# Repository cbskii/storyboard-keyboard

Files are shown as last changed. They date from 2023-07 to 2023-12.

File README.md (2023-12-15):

# Storyboard Keyboard PCB

The "Storyboard" is a 5x12 ortholinear keyboard with an E-Paper display in the middle. This is a hobby project so I've designed the keyboard with learning and experimentation in mind. Most components are SMT and can be assembled by the PCB manufacturer for added cost leaving only a few headers to be soldered by hand. The `production_files` directory contains gerber files and a BOM needed for PCB manufacturing.

## Features
- Ortholinear "split" 5x12 key arrangement.
- Hot swap key switches with split FR4 plates.
- Fits standard sized 60% keyboard cases that use a USB daughterboard (e.g. Tofu60 and Bakeneko60).
- E-Paper display for personalization. The [3.7" Waveshare e-Paper HAT](https://www.waveshare.com/3.7inch-e-paper-hat.htm) fits the best and is supported by the firmware, but the 3.52" would work as well if firmware support is added. Last set image will remain even when keyboard is unplugged/powered off (but recommended to refresh the display every now and then by rebooting the keyboard).
- USB daughterboard support (e.g. [Unified Daughterboard](https://github.com/Unified-Daughterboard/)).
- Support for different [Sparkfun Micromod](https://www.sparkfun.com/micromod) processor boards allowing for easy swap of the underlying MCU and related functionality (requires firmware change).
- QMK firmware ([development branch](https://github.com/cbskii/qmk_firmware/tree/master/keyboards/storyboard)).
- Shift register based key matrix that requires only 4 GPIOs.
- Key press interrupt support to enable lower power usage modes.

## Inspiration
- [Lumberjack](https://github.com/peej/lumberjack-keyboard)
- [Ghoul](https://github.com/tzarc/ghoul)
- [Bakeneko 60](https://github.com/kkatano/bakeneko-60)

## Pictures
storyboard-space
storyboard-rev1-front
storyboard-rev1-back

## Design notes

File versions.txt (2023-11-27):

Revision History
----------------
1.0: Initial Schematic and PCB.
1.1: Add top mount plates for Tofu60. Move from 3.52" display to 3.7".

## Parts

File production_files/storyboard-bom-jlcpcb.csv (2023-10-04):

Comment | Designator | Footprint | JLCPCB Part # | SMD Assembly
Kailh_socket_MX | SW51,SW16,SW9,SW35,SW28,SW19,SW38,SW11,SW15,SW47,SW17,SW23,SW41,SW13,SW44,SW45,SW56,SW8,SW59,SW34,SW26,SW36,SW25,SW50,SW54,SW53,SW37,SW18,SW4,SW46,SW33,SW14,SW52,SW3,SW58,SW40,SW43,SW55,SW12,SW6,SW21,SW48,SW32,SW5,SW39,SW49,SW20,SW7,SW29,SW57,SW10,SW42,SW27,SW24,SW60,SW30,SW31,SW1,SW22,SW2 | Kailh_socket_MX | C5156480 | Yes
AP7361C-33E | U4 | SOT-223-3_TabPin2 | C500795 | Yes
10k | R11,R6,R16,R14,R20,R12,R18,R1,R19,R8,R13,R17,R15,R5,R7,R10,R9,R3,R4,R2 | R_0805_2012Metric | C2930231 | Yes
1N4148 | D8,D35,D56,D21,D9,D33,D57,D7,D34,D62,D36,D15,D11,D17,D29,D39,D49,D40,D63,D59,D24,D32,D12,D20,D42,D38,D46,D4,D45,D47,D28,D54,D61,D50,D58,D22,D66,D13,D68,D72,D41,D44,D69,D70,D65,D6,D10,D31,D67,D73,D3,D18,D16,D23,D2,D30,D25,D1,D60,D5,D26,D51,D27,D55,D71,D52,D64,D37,D43,D53,D14,D48,D19 | D_SOD-523 | C727112 | Yes
74HC165 | U3,U2 | SOIC-16_3.9x9.9mm_P1.27mm | C5613 | Yes
CONN HEADER SMD 4POS 1.2MM | J2 | CONN HEADER SMD 4POS 1.2MM | C588524 | Yes
74HC164 | U1 | SOIC-14_3.9x8.7mm_P1.27mm | C5419 | Yes
4.7uF | C4,C5 | C_0805_2012Metric | C98192 | Yes
0.1uF | C3,C2,C1 | C_0805_2012Metric | C126469 | Yes
CONN M.2 FMALE 67POS 0.020 GOLD | J3 | M.2-CONNECTOR-E | C2977809 | Yes
BOOT Switch | SW62 | SW_PUSH_6mm |  | No
RESET Switch | SW61 | SW_PUSH_6mm |  | No
Debug Breakout | J1 | PinHeader_1x05_P2.54mm_Vertical |  | No
Conn_02x20_Odd_Even | J4 | Waveshare_ePaper_HAT_352 |  | No
M2.5 Standoff | J5 | Micromod-Standoff |  | No

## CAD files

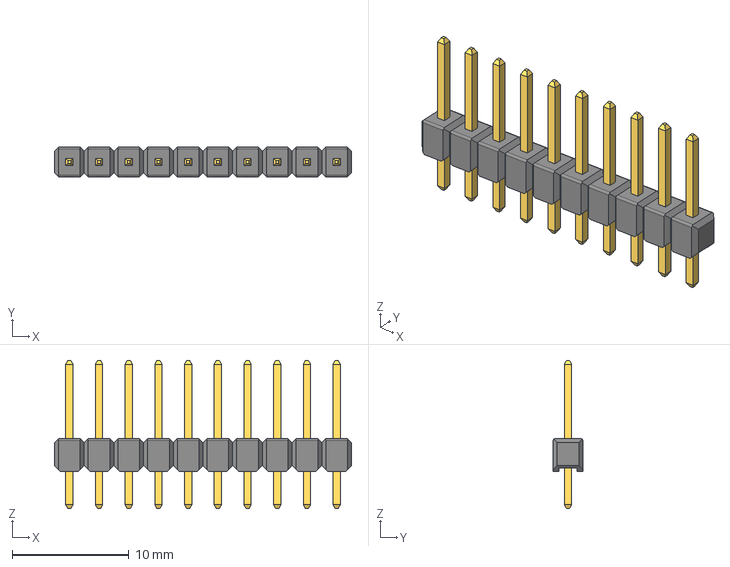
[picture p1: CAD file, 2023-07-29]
storyboard/Pin Header 1x10 TH Pitch 2.54mm.stp
25.4 x 2.54 x 12.7 mm

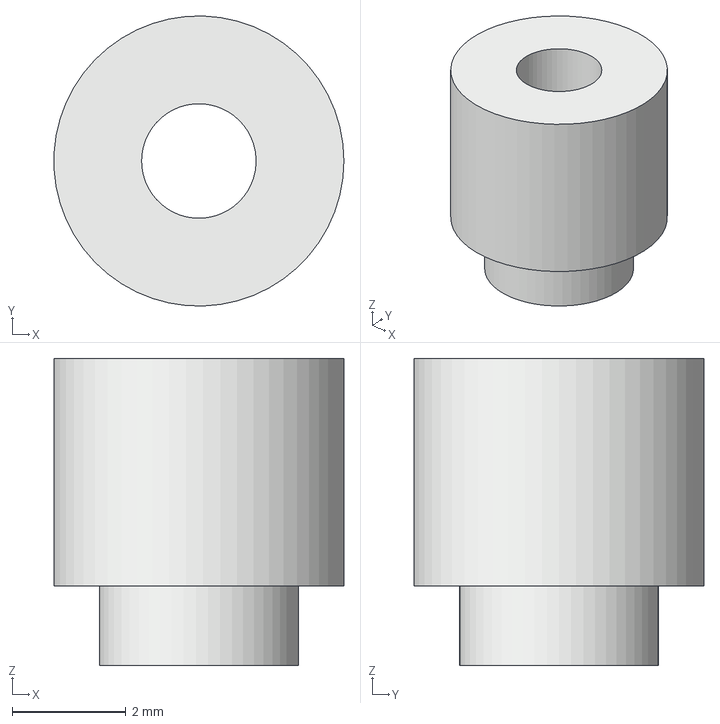
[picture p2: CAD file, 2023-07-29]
storyboard/WA-SMSI-9774040151.stp
5.10 x 5.10 x 5.40 mm

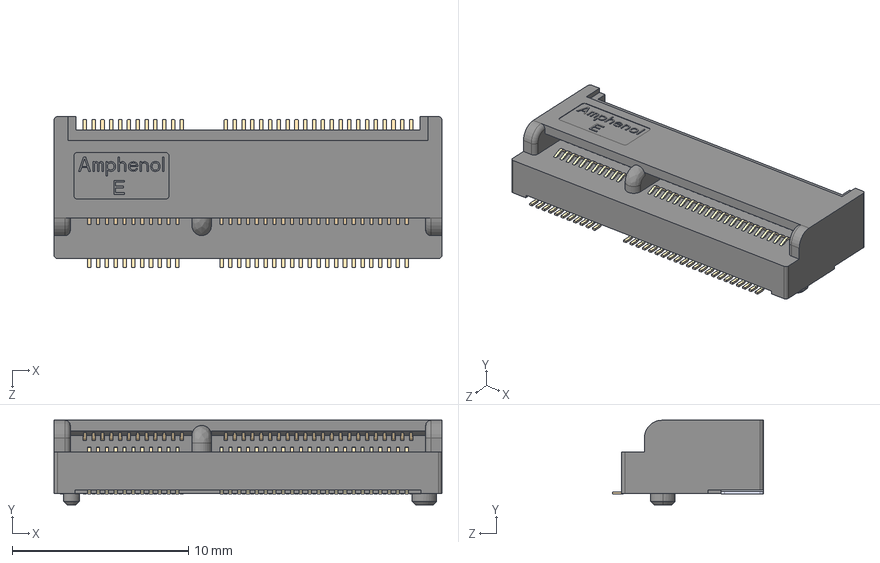
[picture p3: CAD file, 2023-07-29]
storyboard/MDT420E03001--3DModel-STEP-269445.STEP
22.0 x 4.80 x 8.55 mm

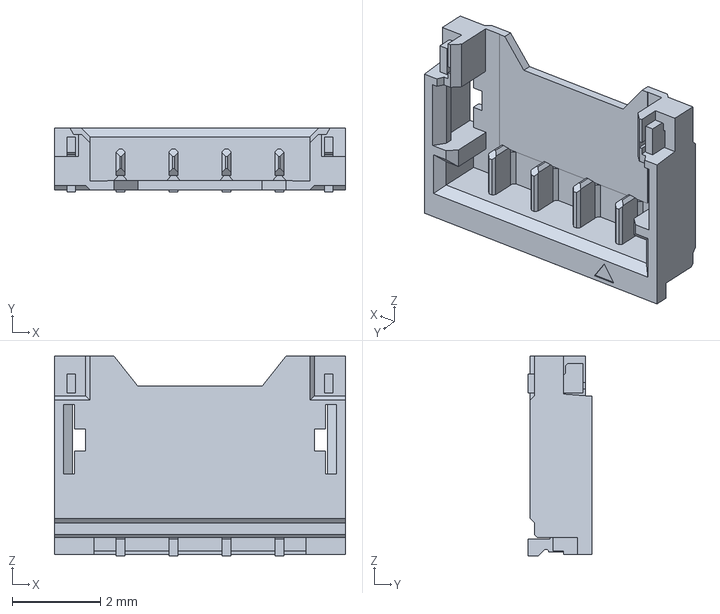
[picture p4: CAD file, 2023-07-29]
storyboard/781710004.stp
6.60 x 1.45 x 4.53 mm

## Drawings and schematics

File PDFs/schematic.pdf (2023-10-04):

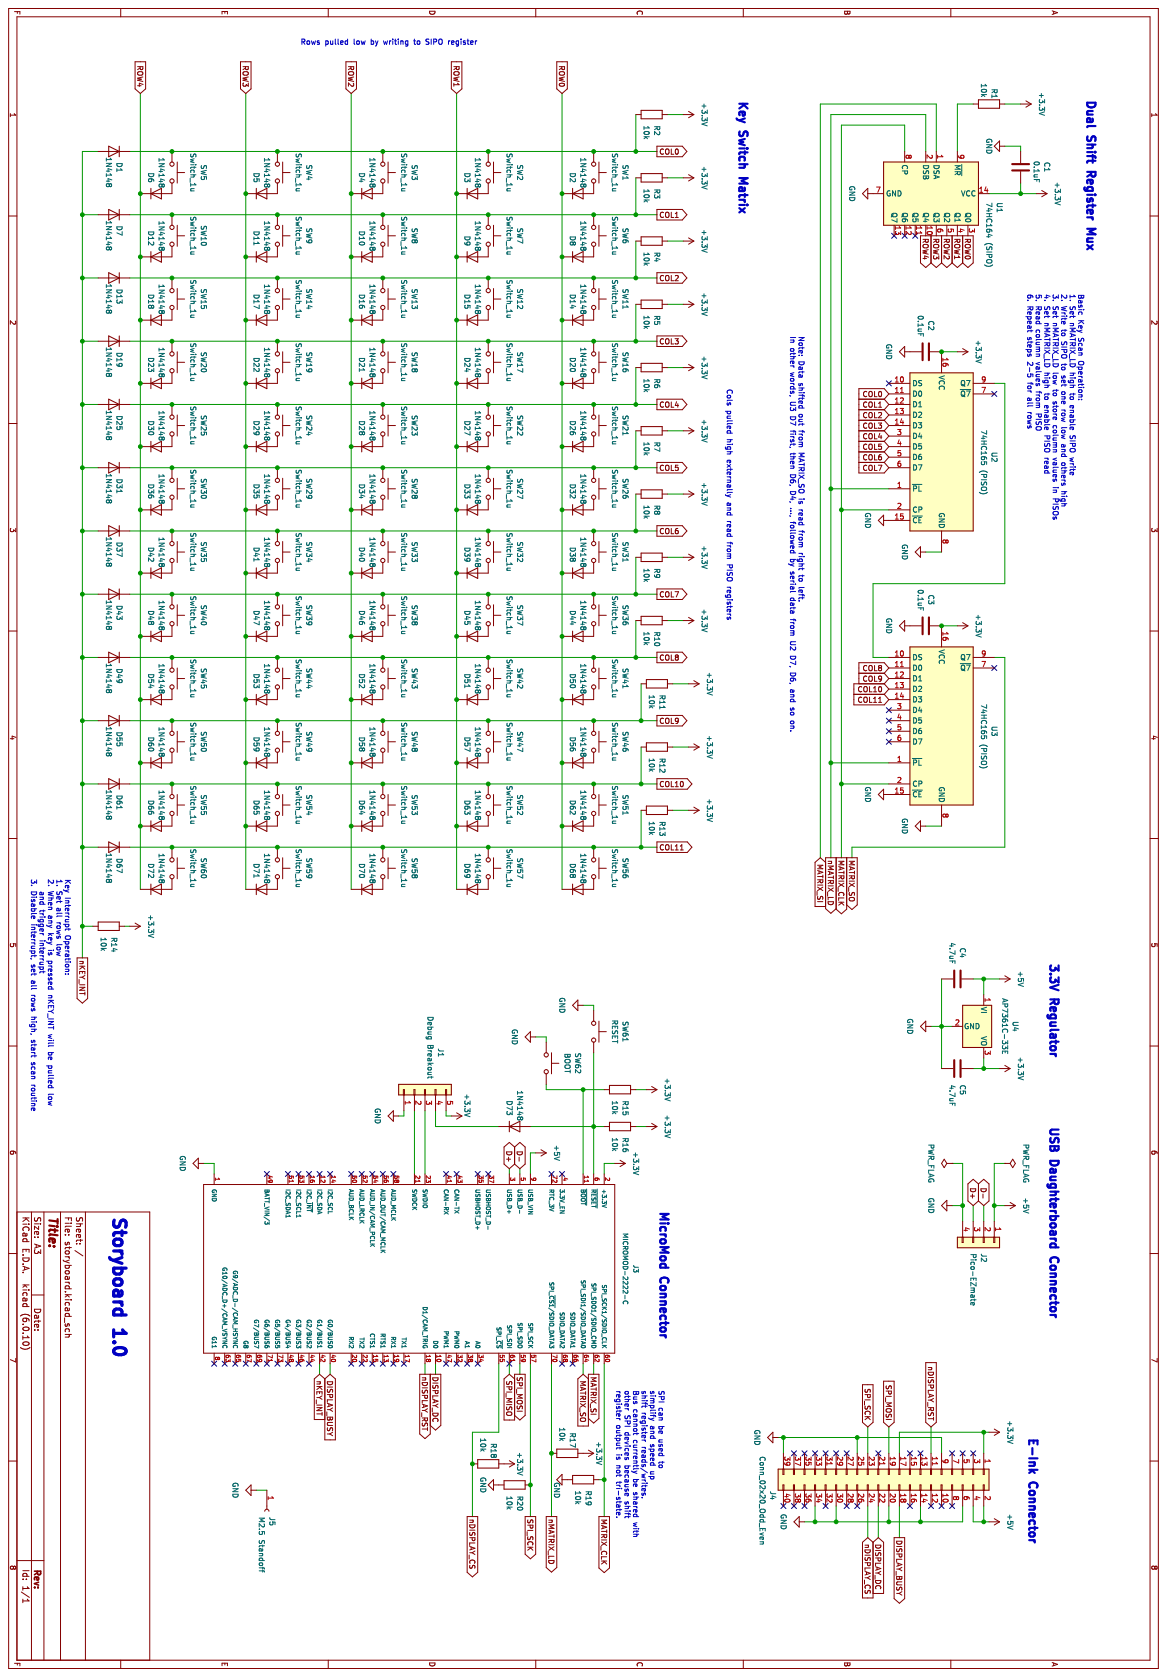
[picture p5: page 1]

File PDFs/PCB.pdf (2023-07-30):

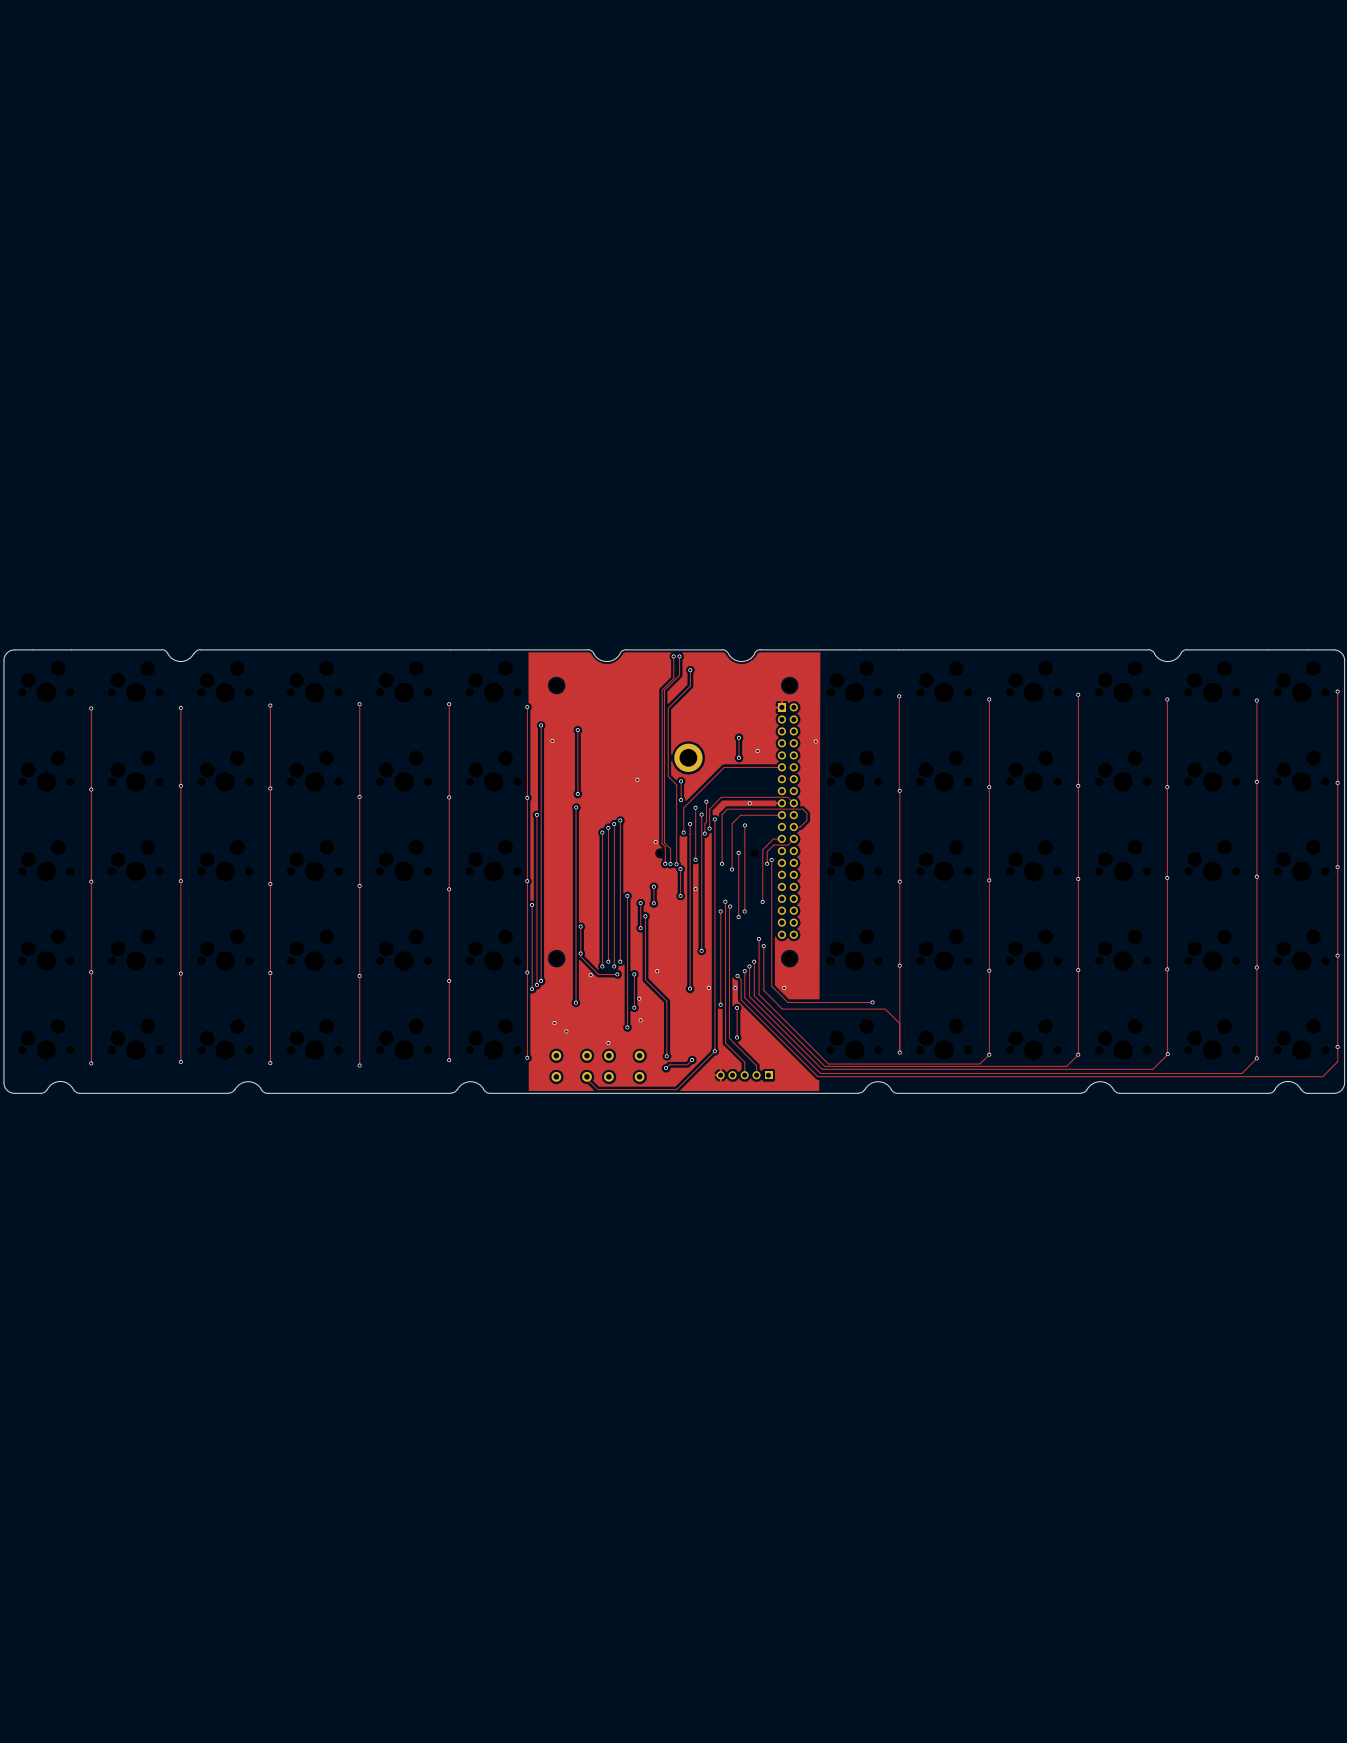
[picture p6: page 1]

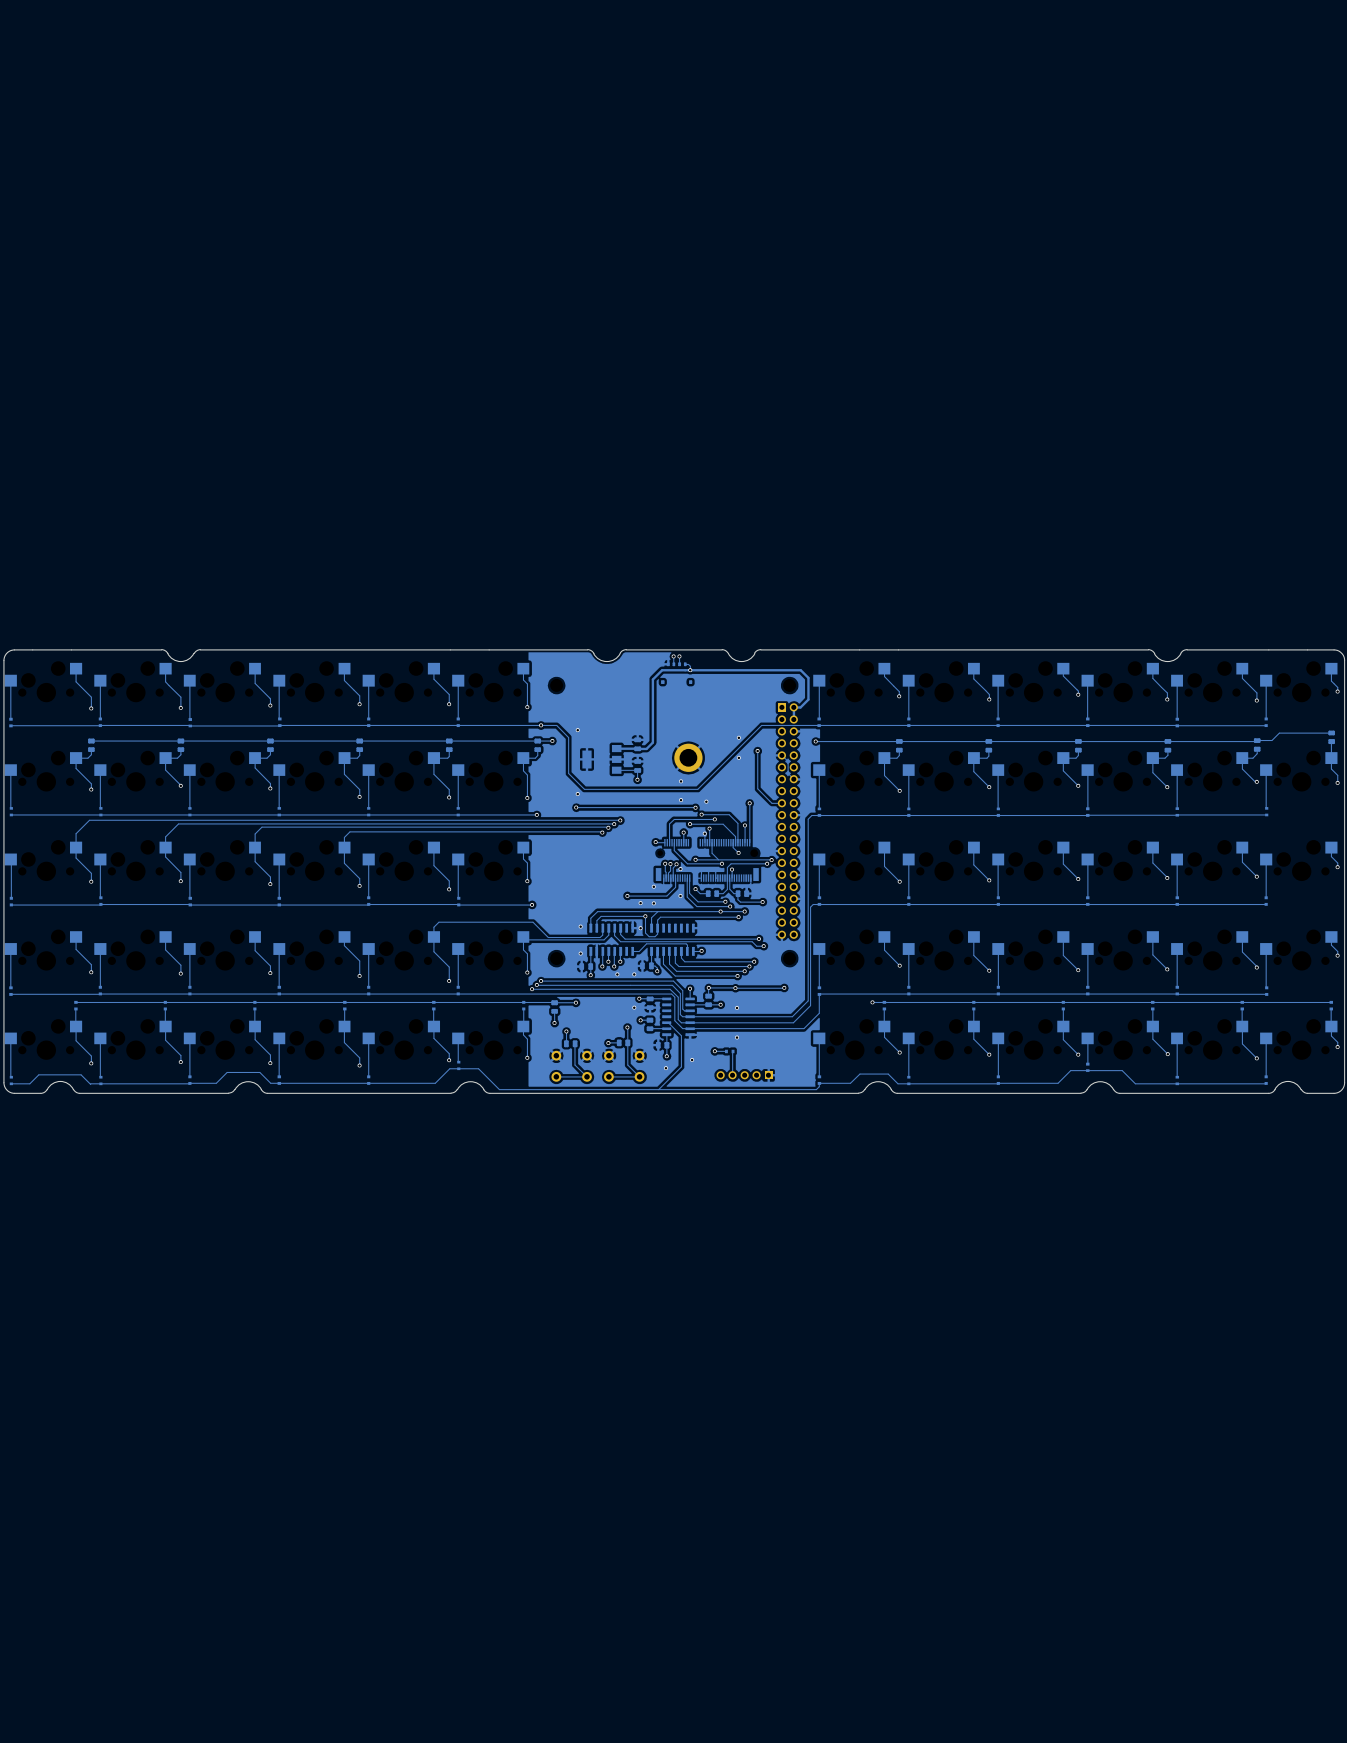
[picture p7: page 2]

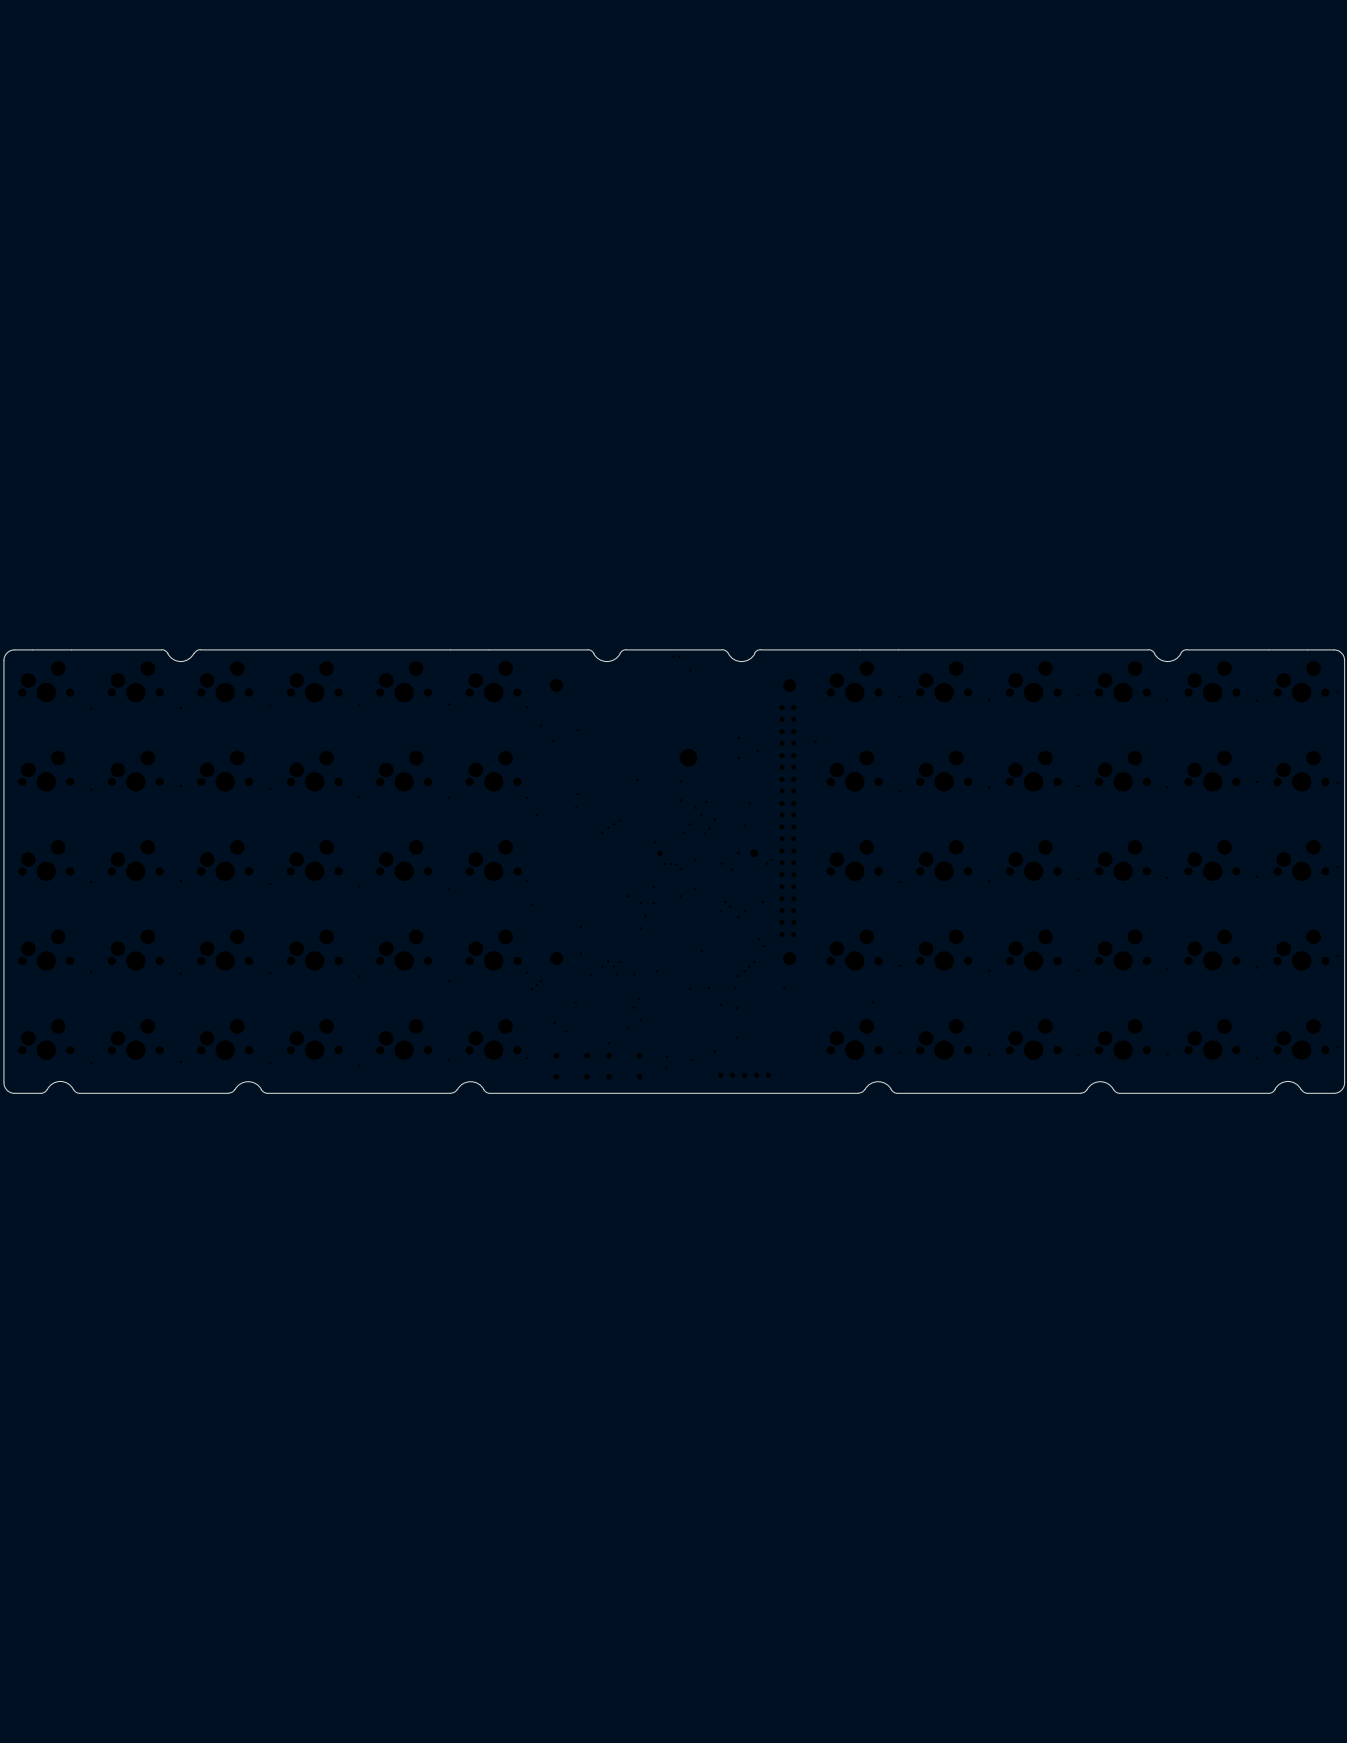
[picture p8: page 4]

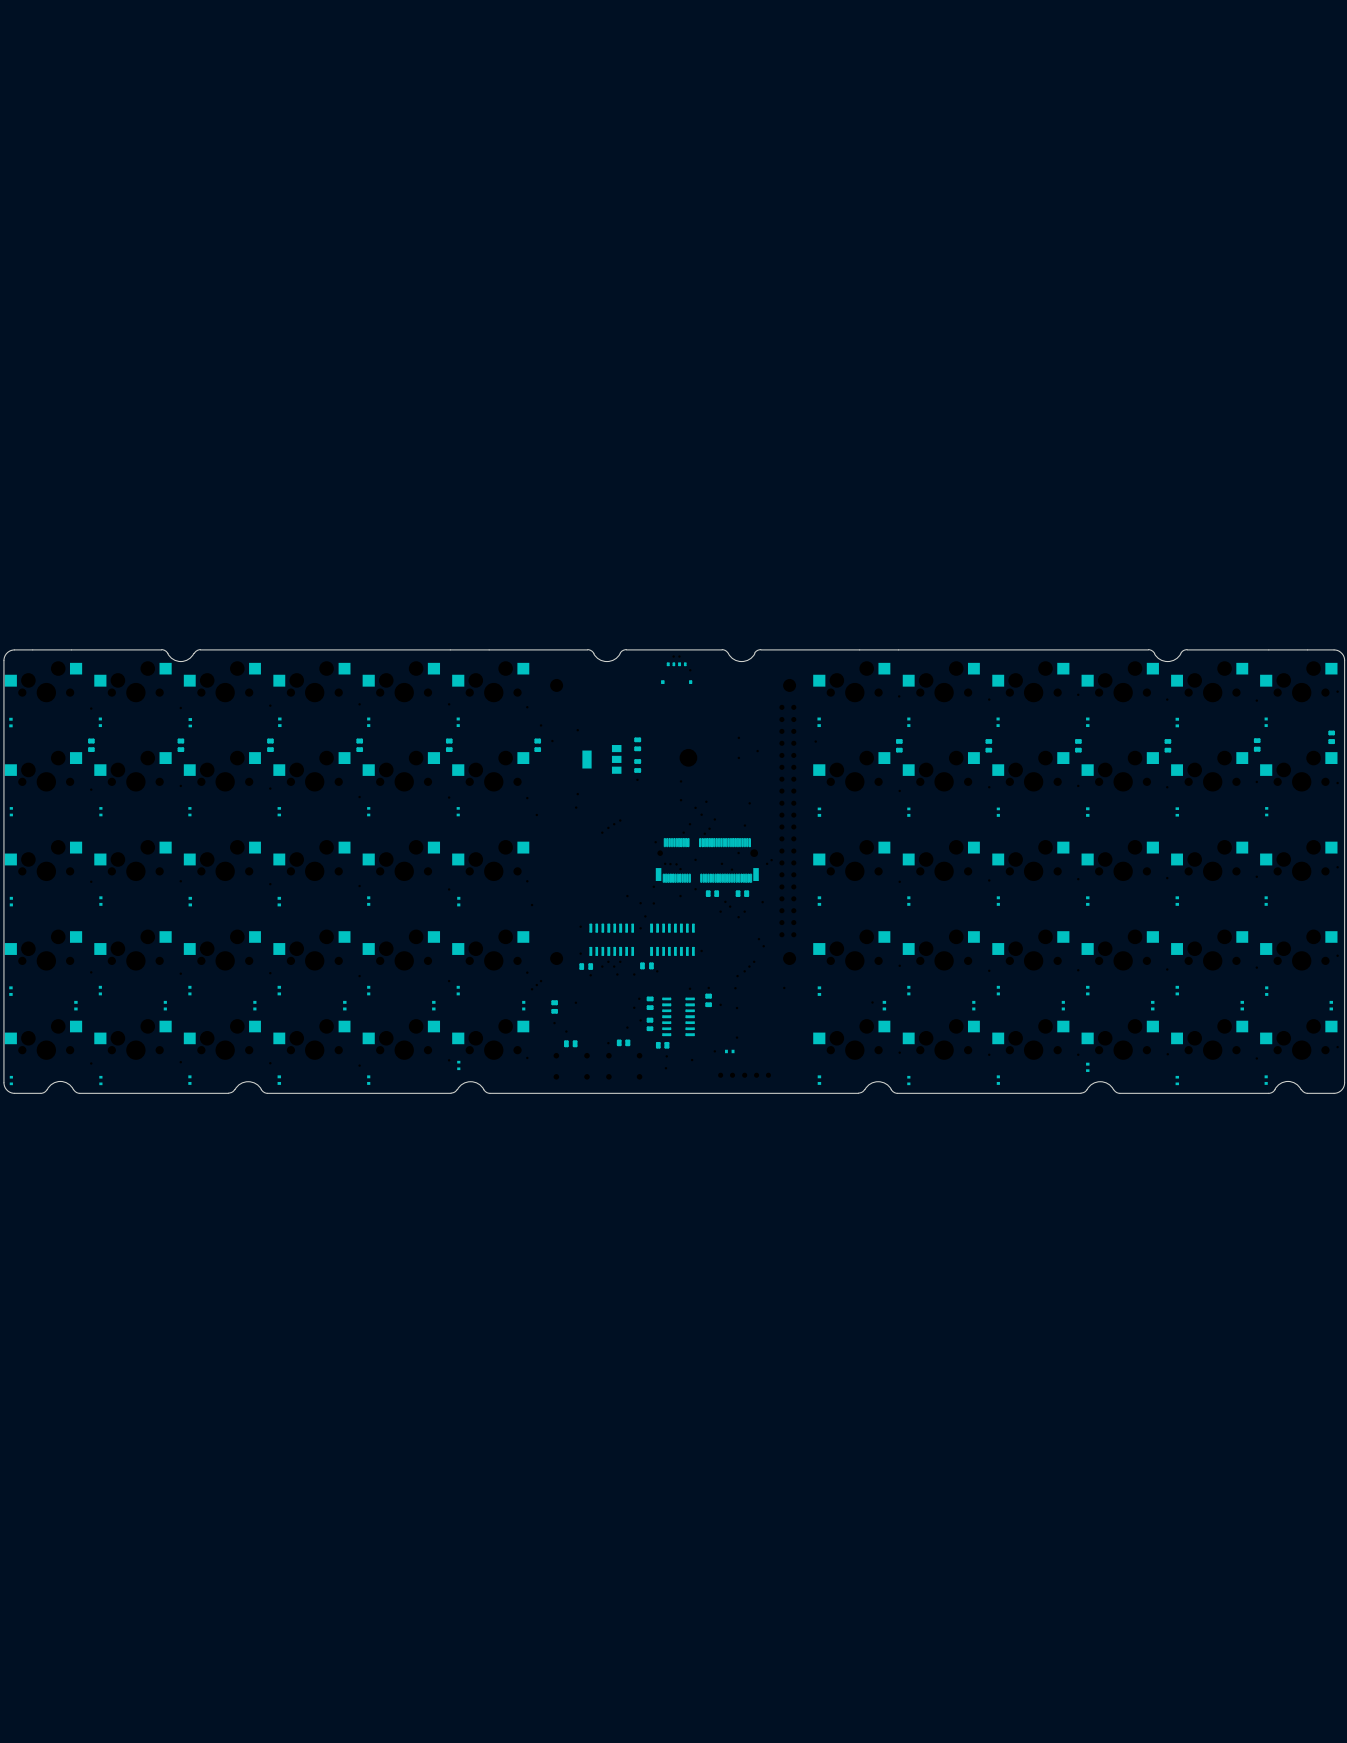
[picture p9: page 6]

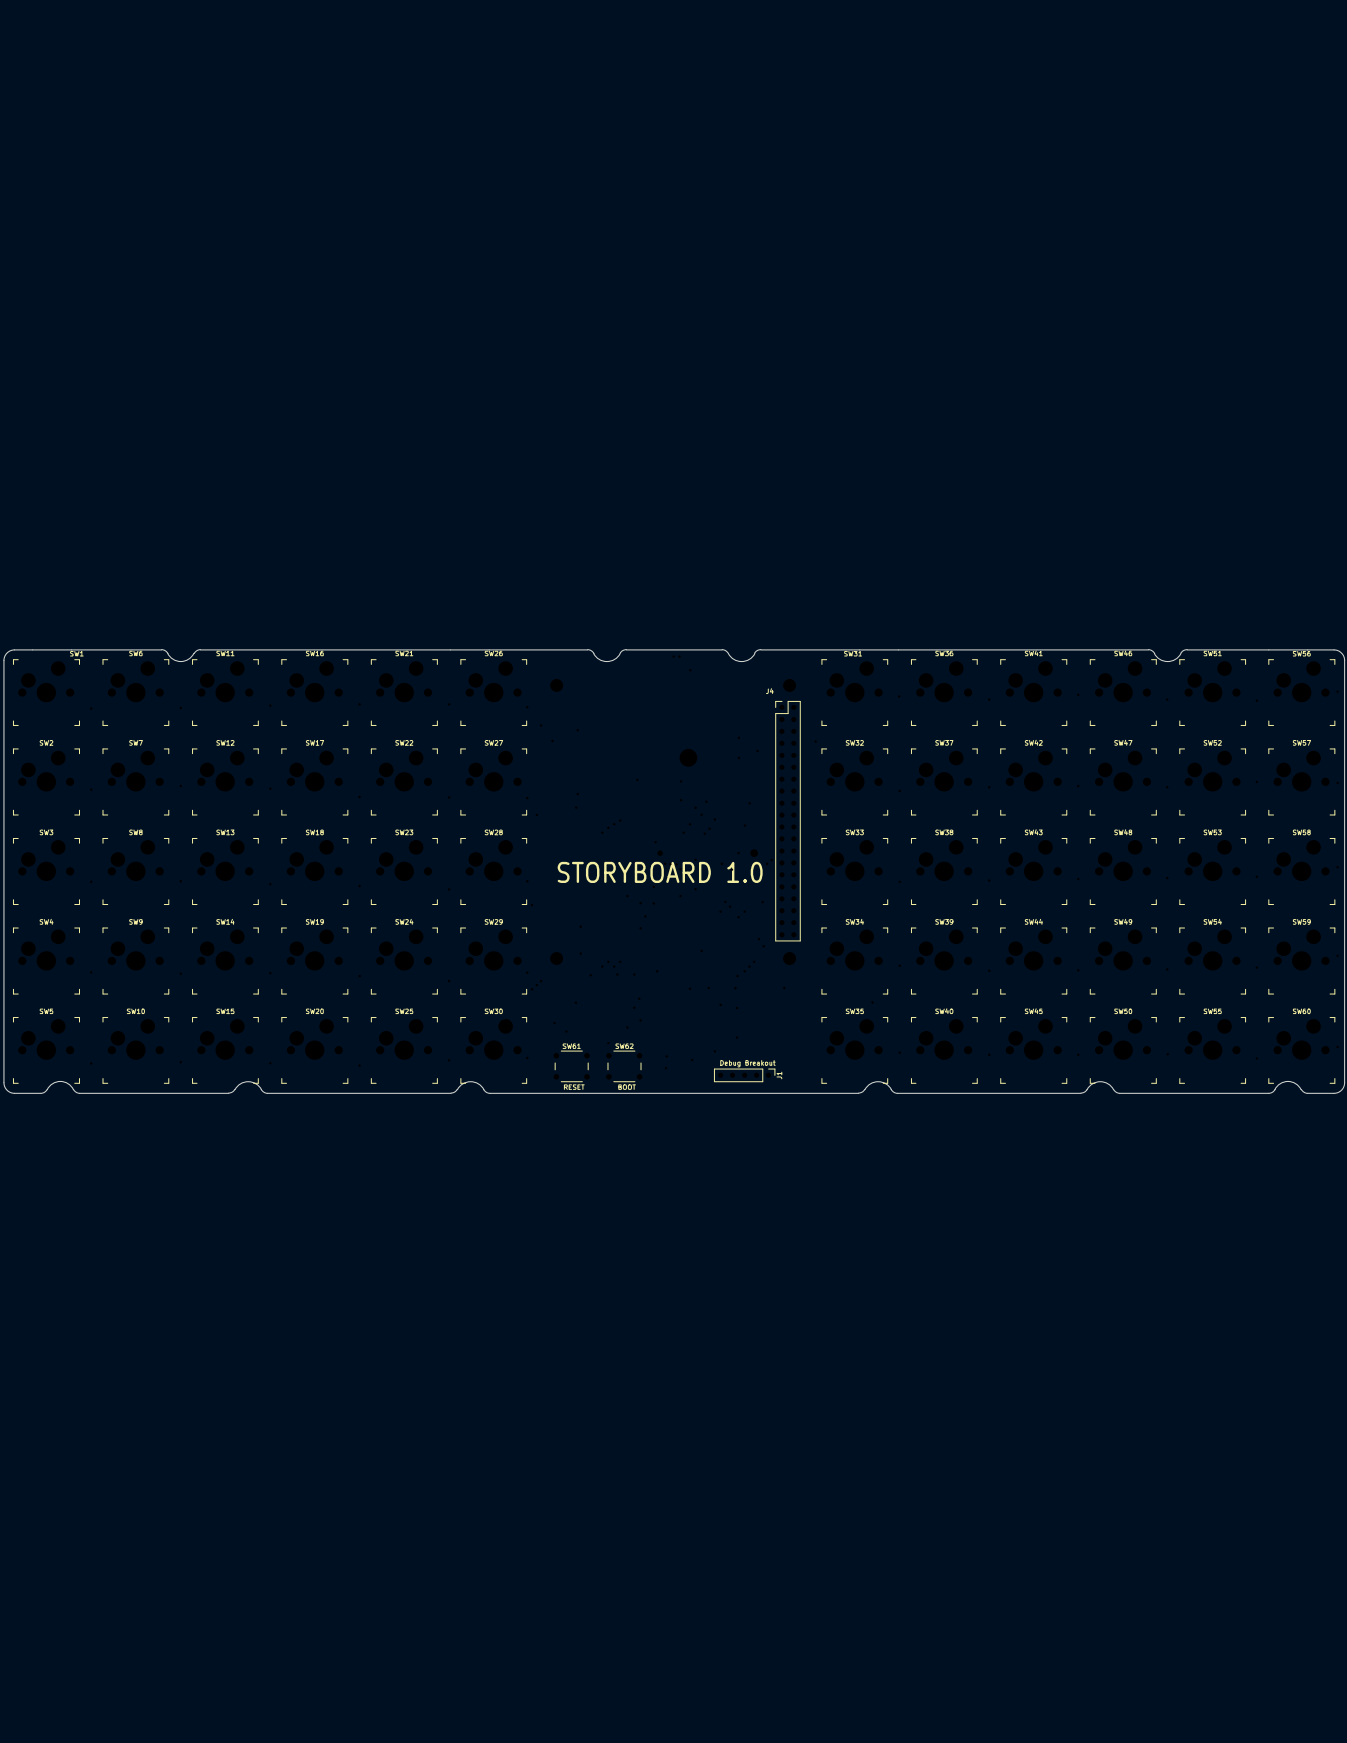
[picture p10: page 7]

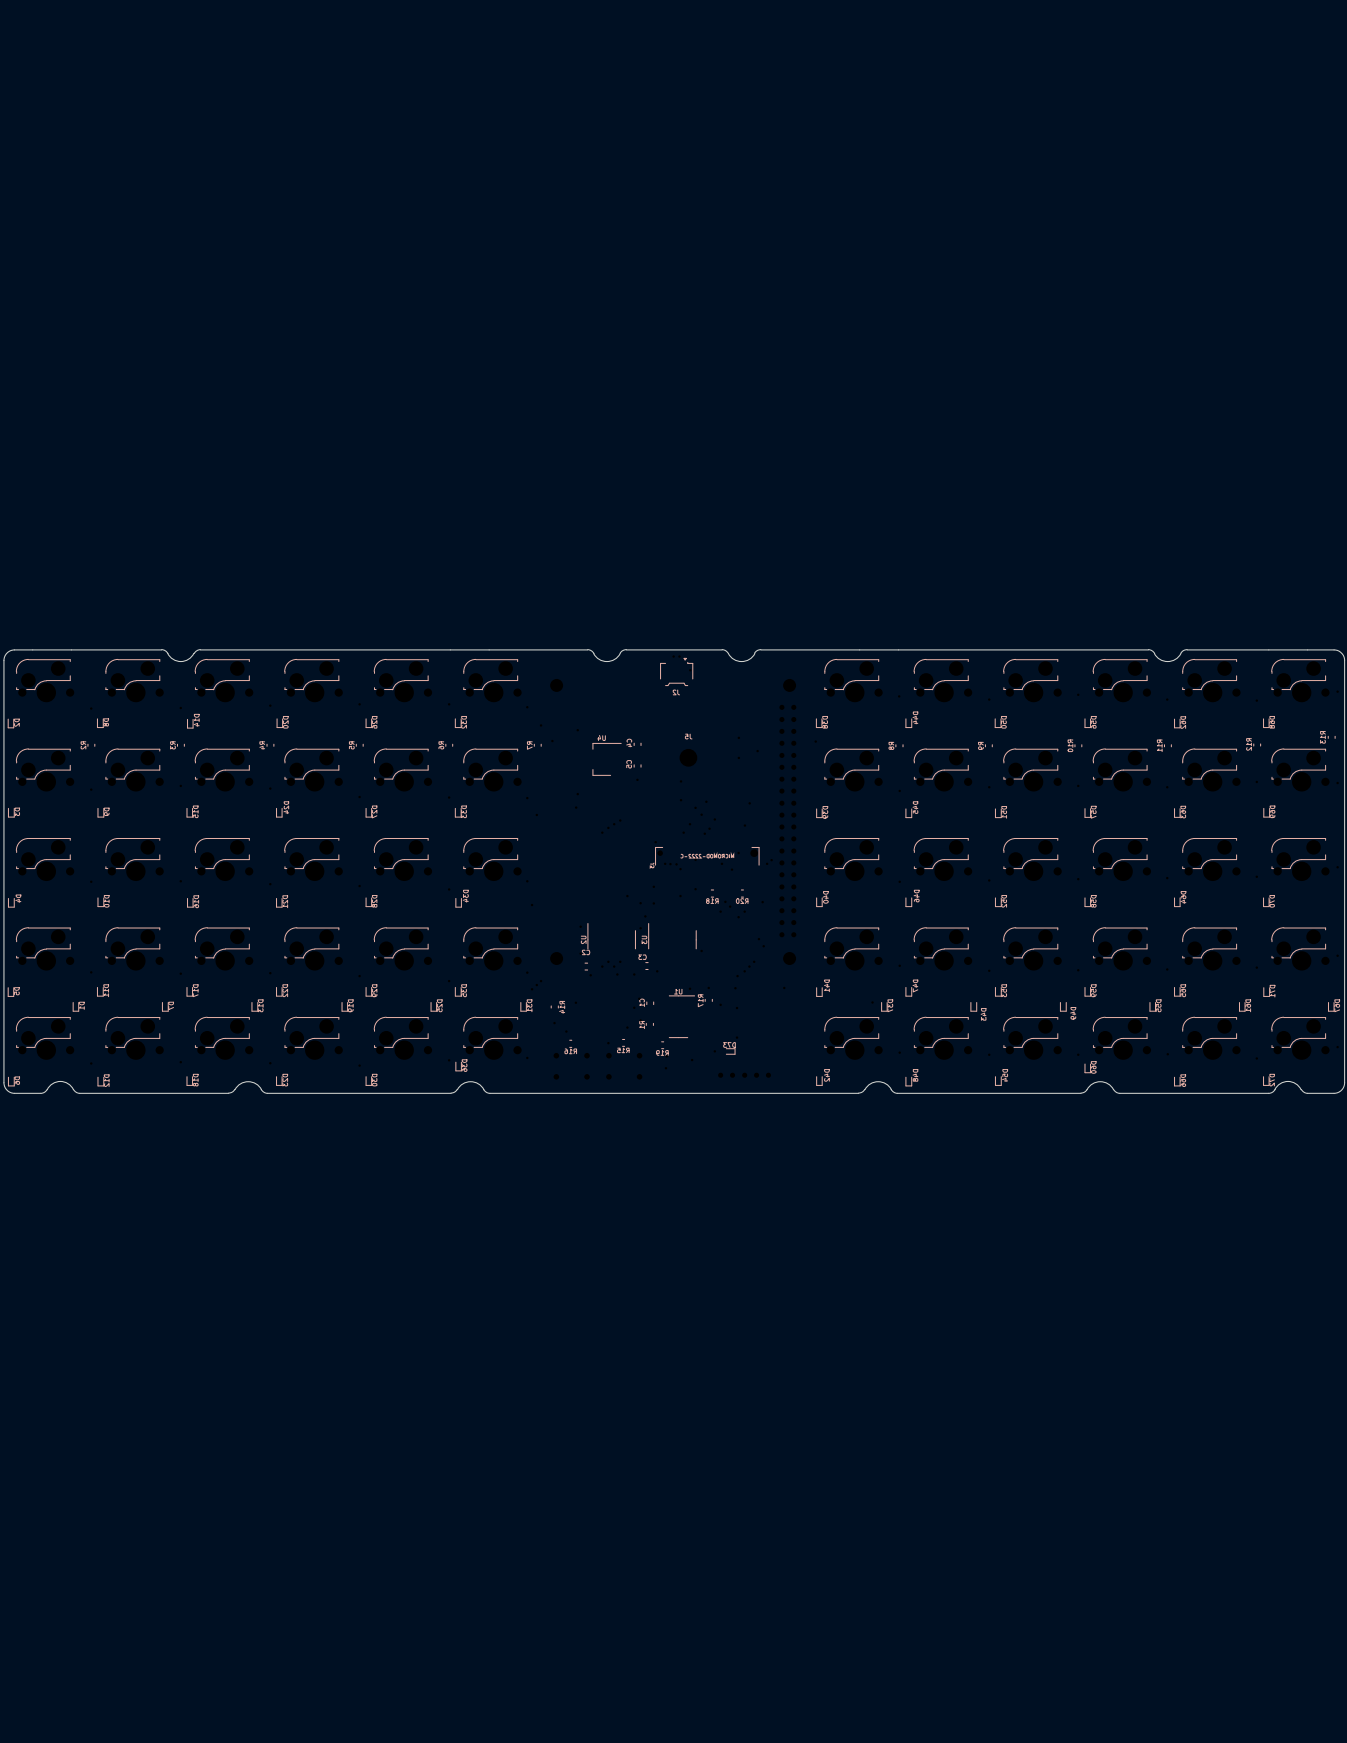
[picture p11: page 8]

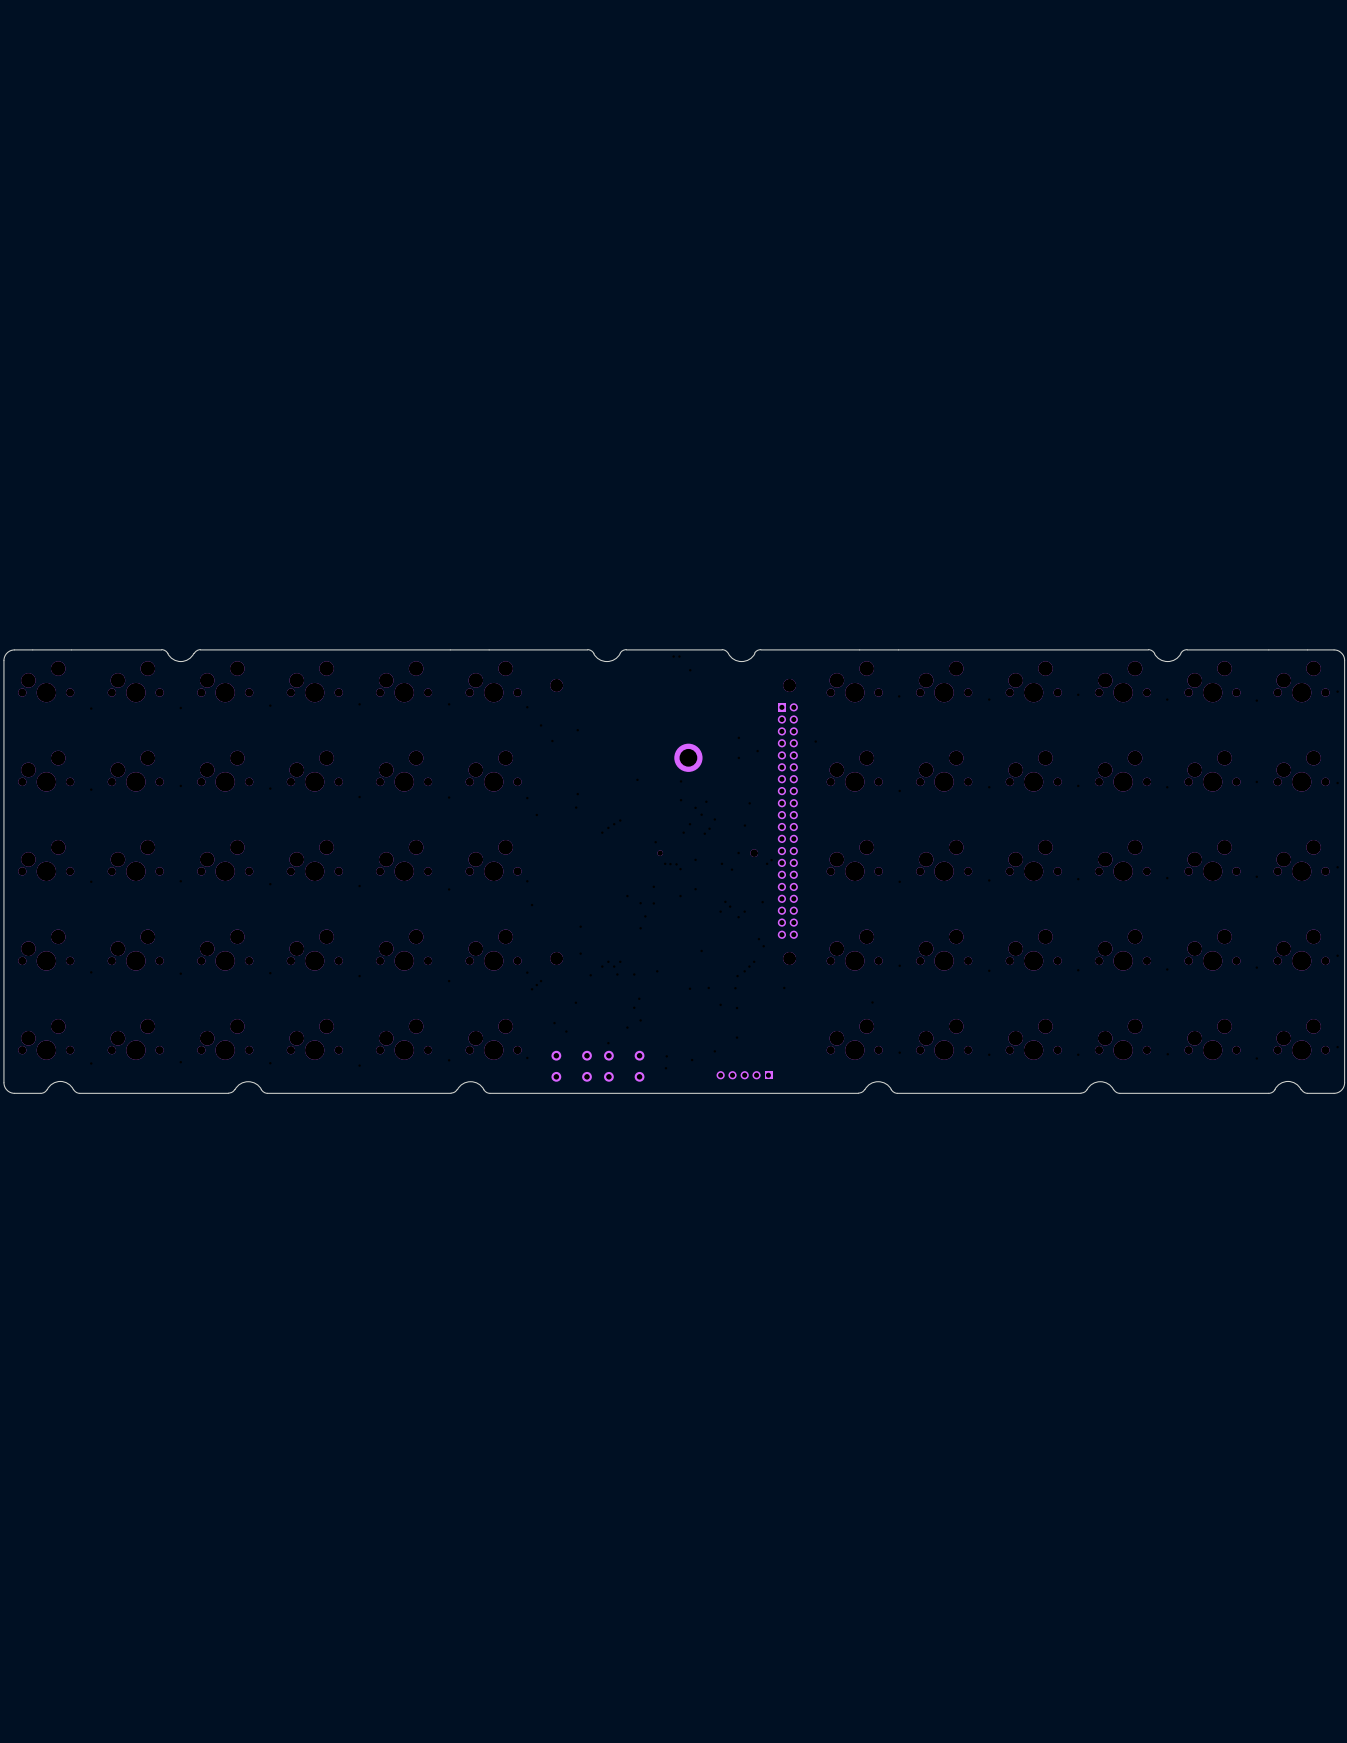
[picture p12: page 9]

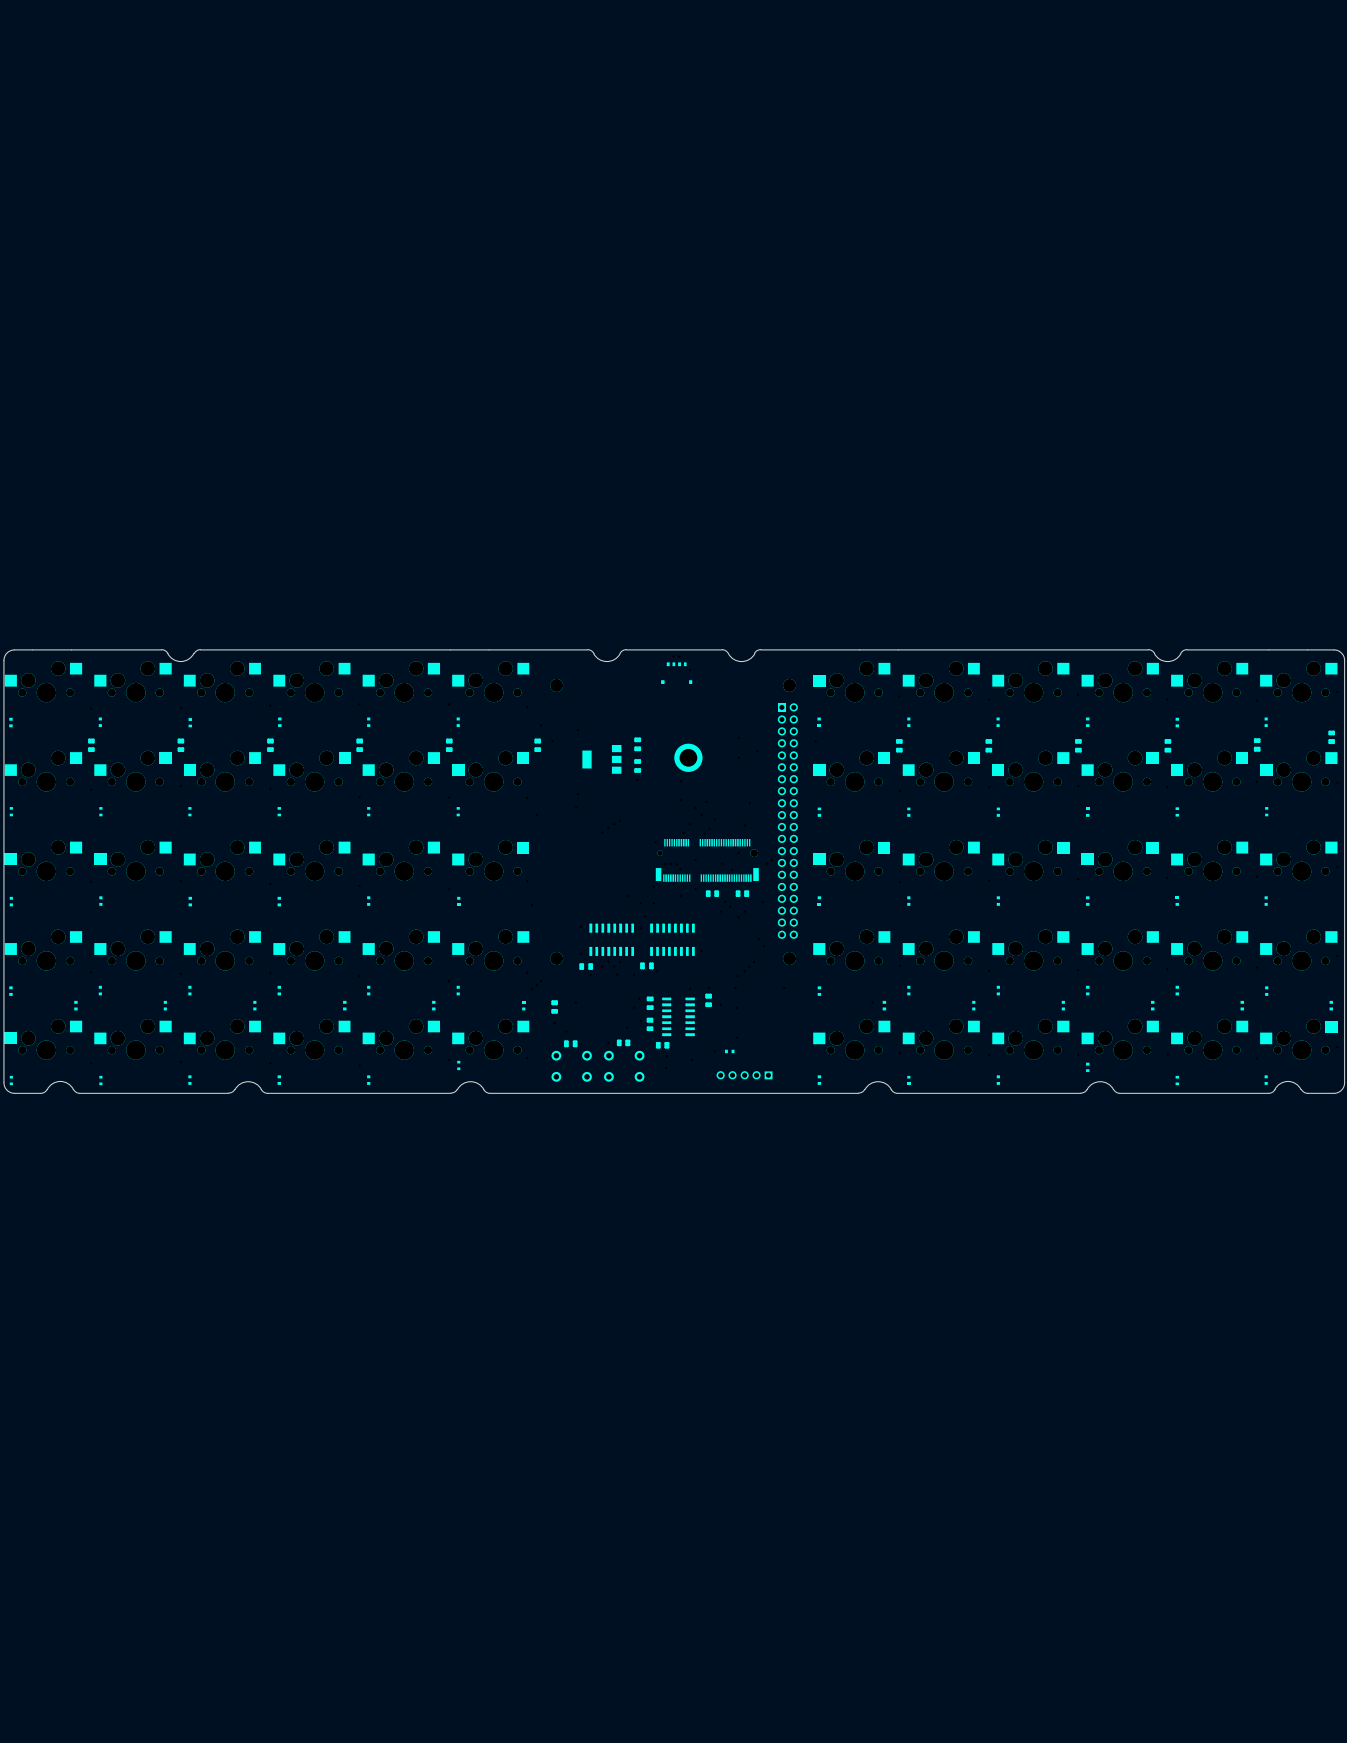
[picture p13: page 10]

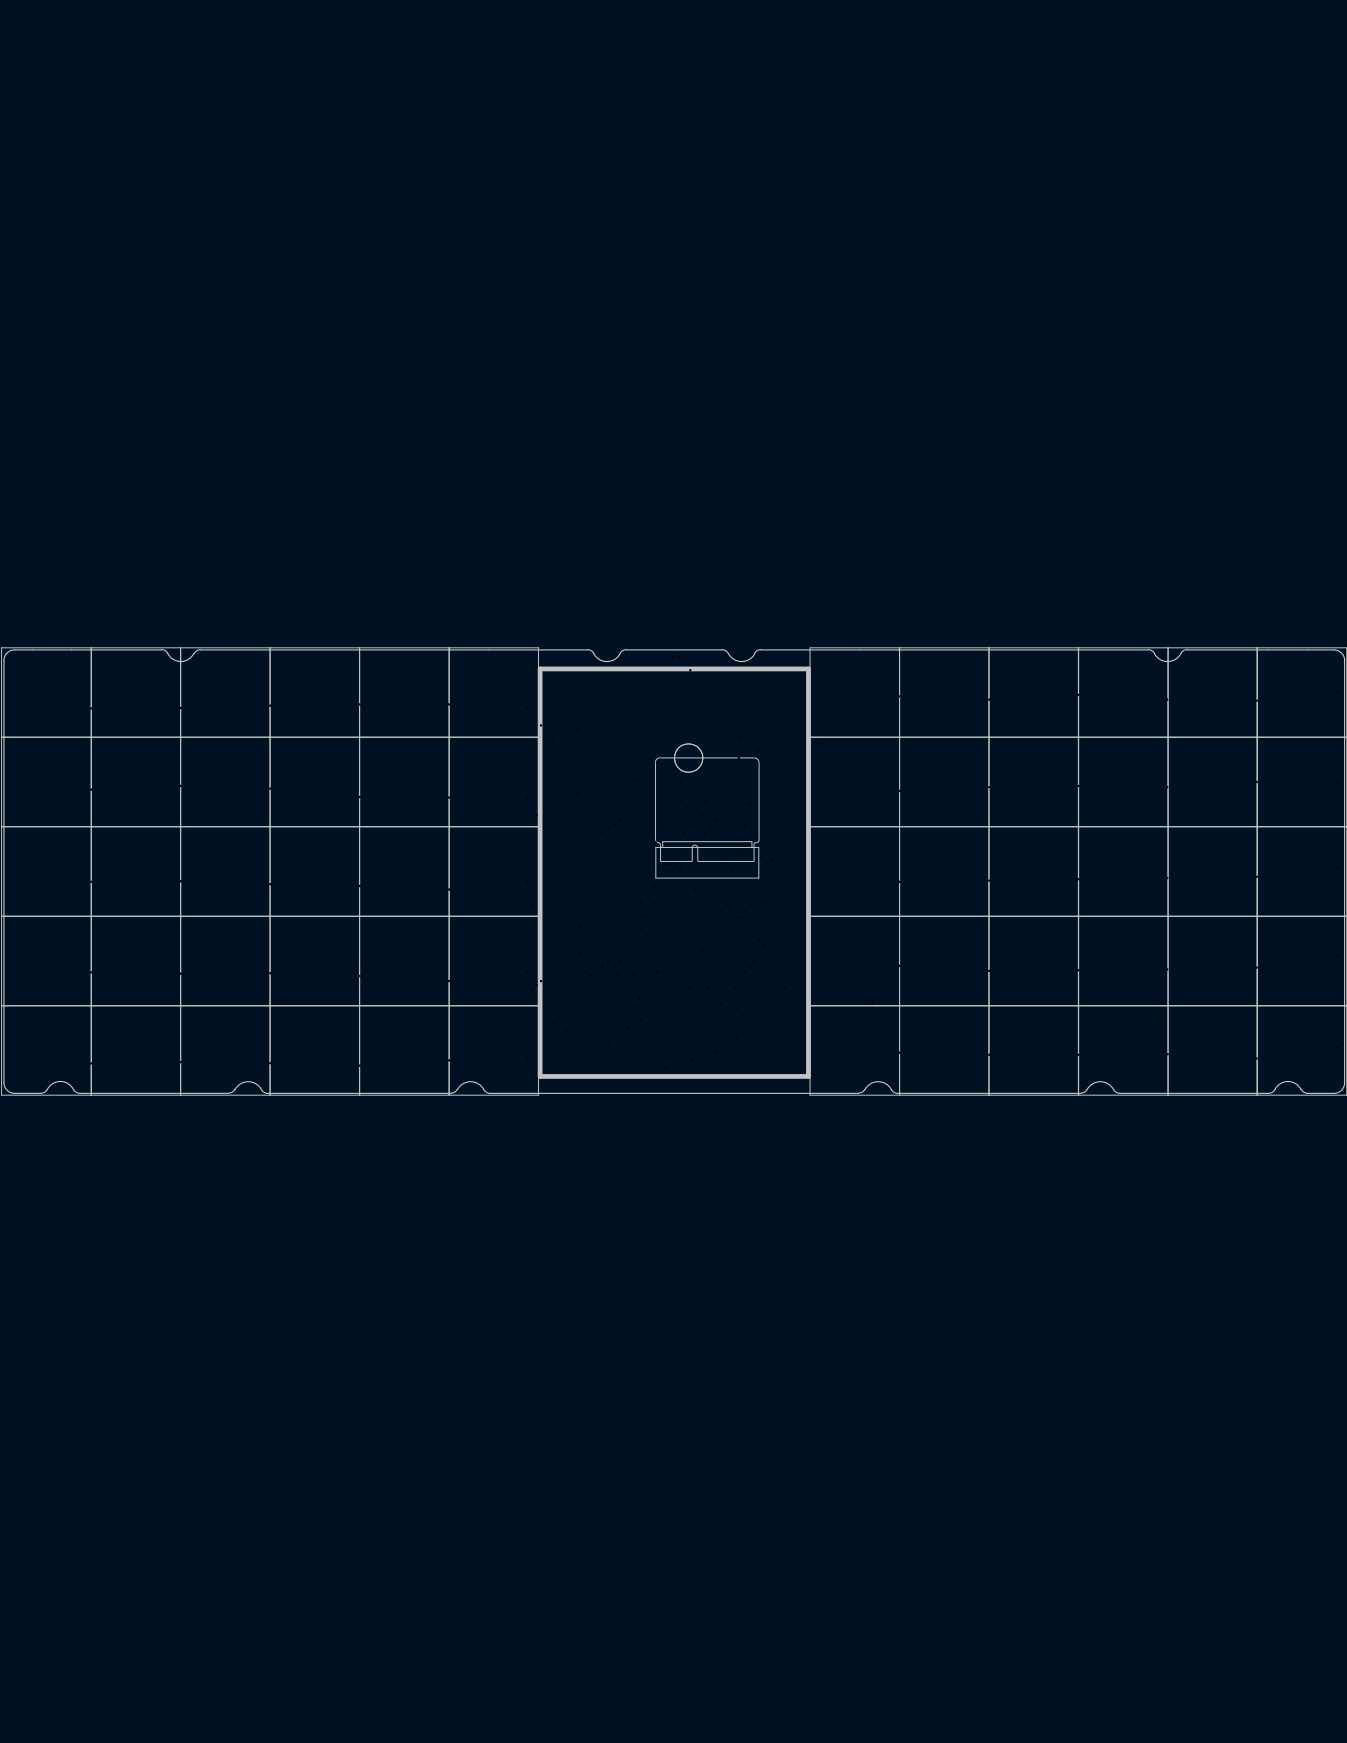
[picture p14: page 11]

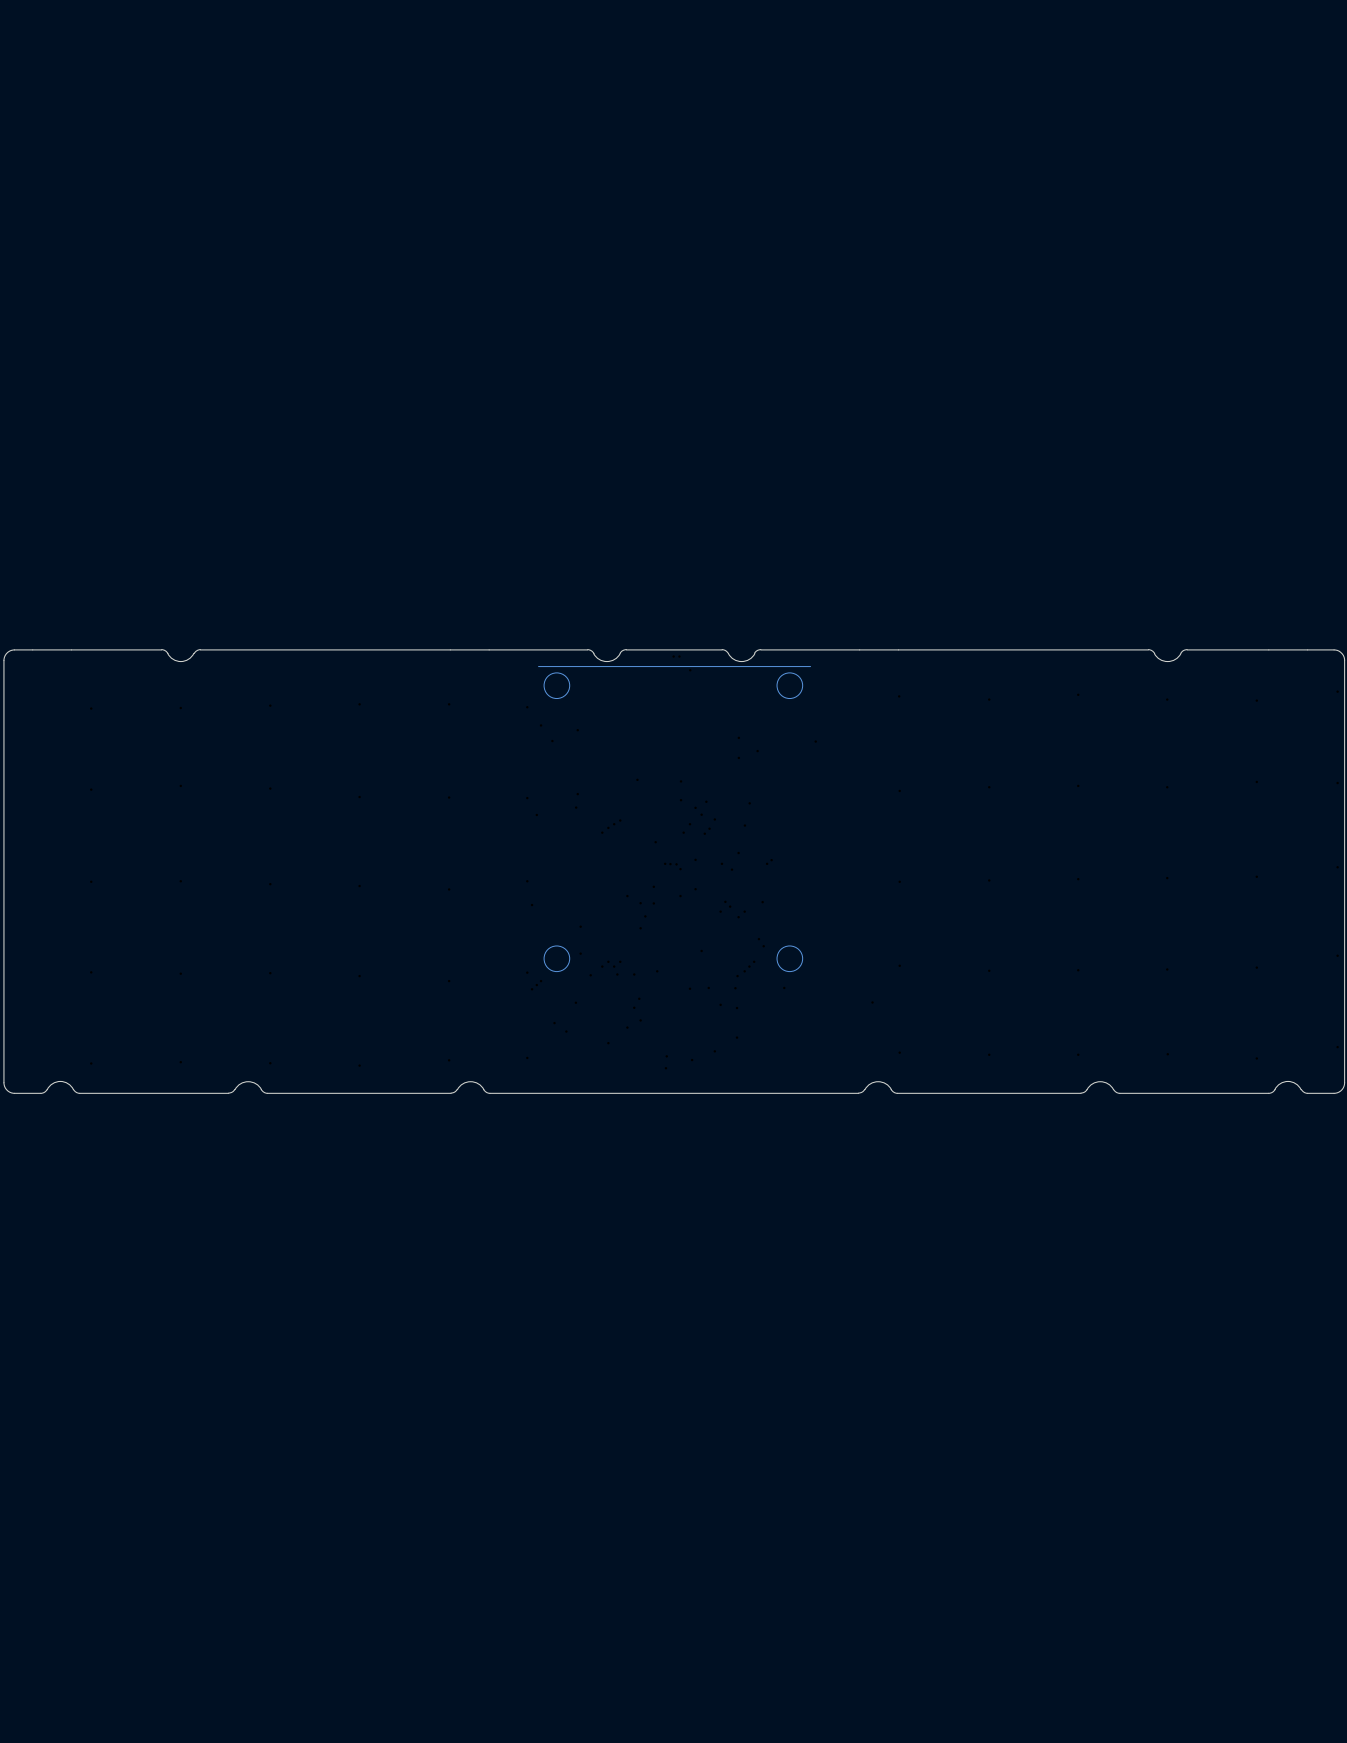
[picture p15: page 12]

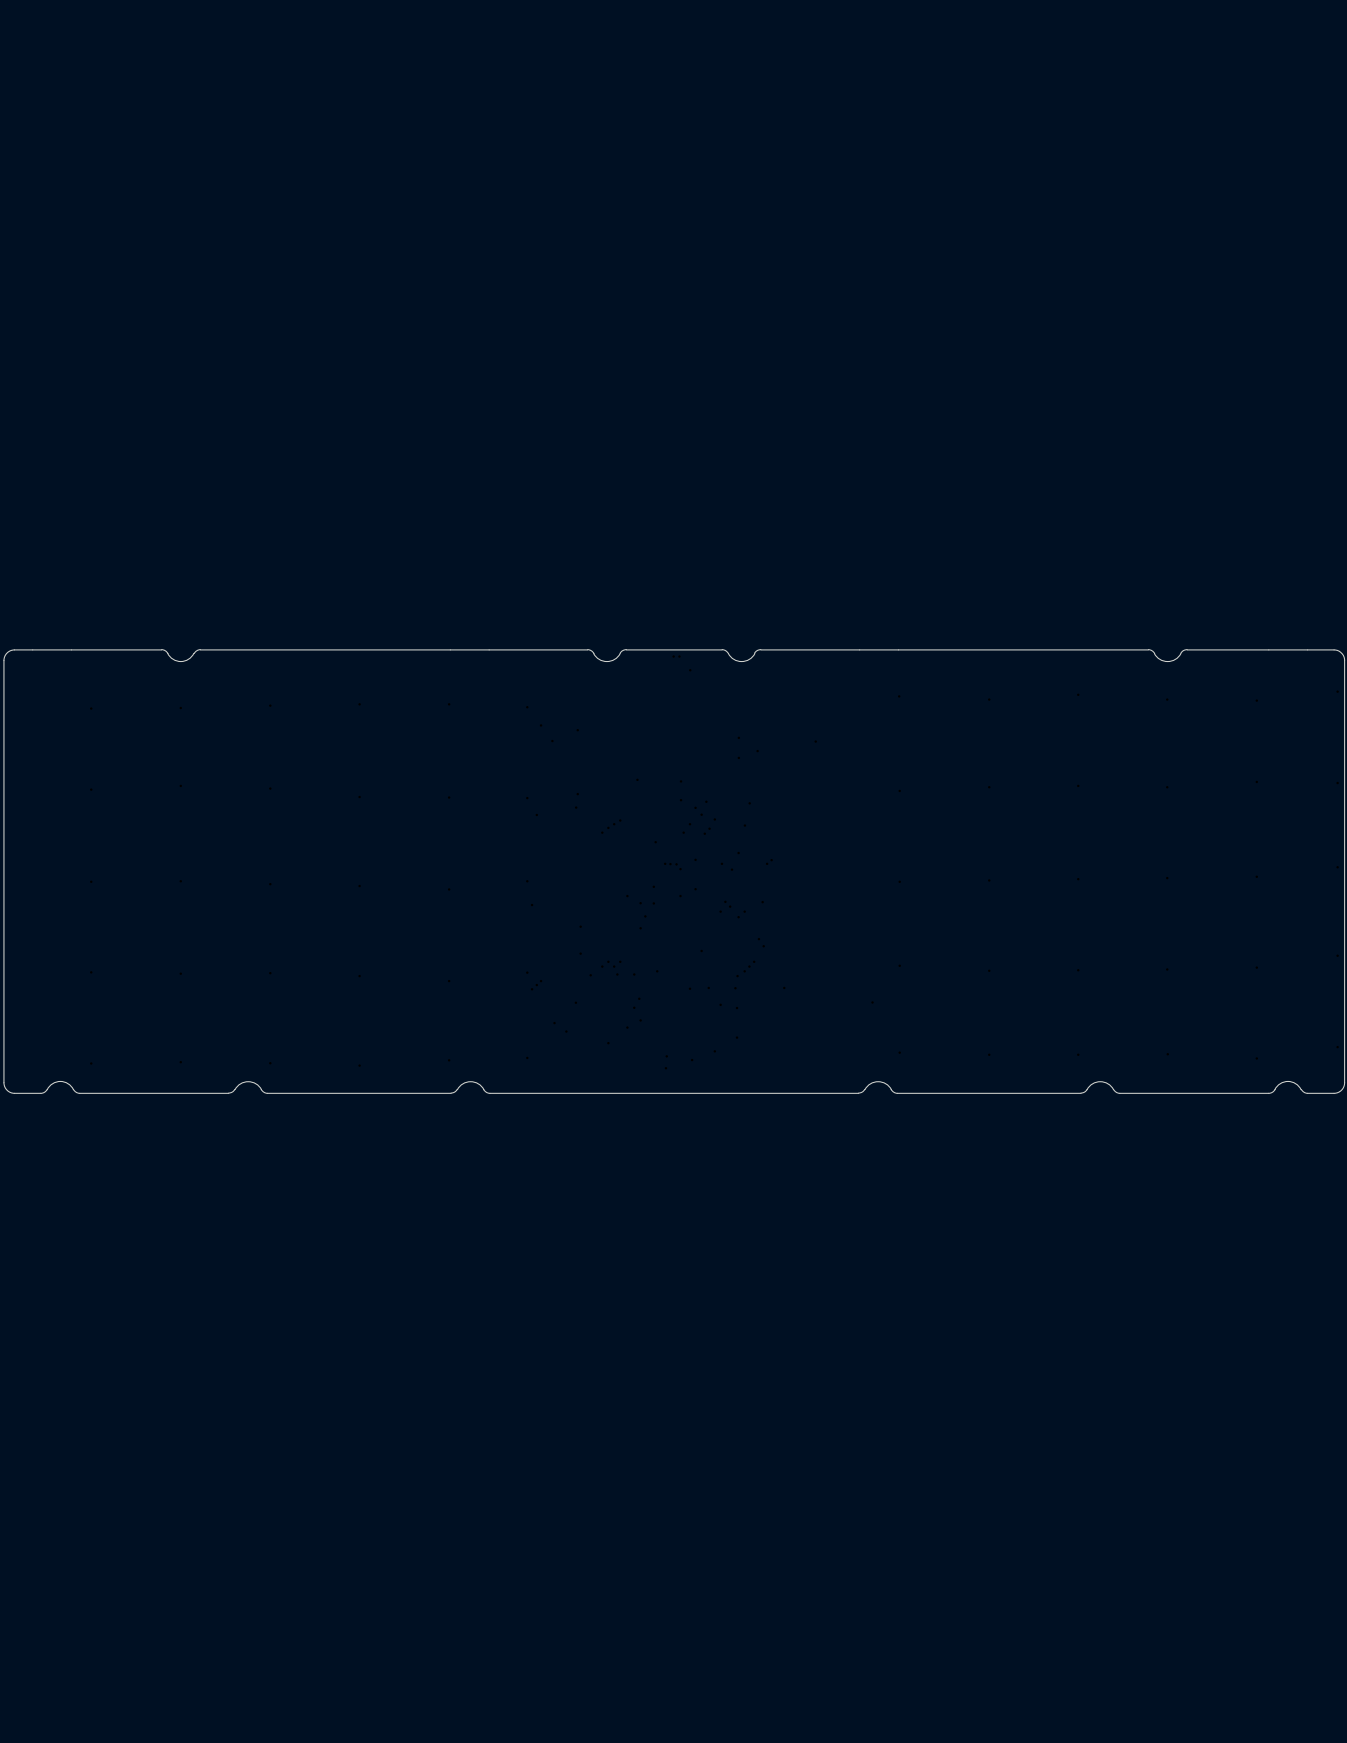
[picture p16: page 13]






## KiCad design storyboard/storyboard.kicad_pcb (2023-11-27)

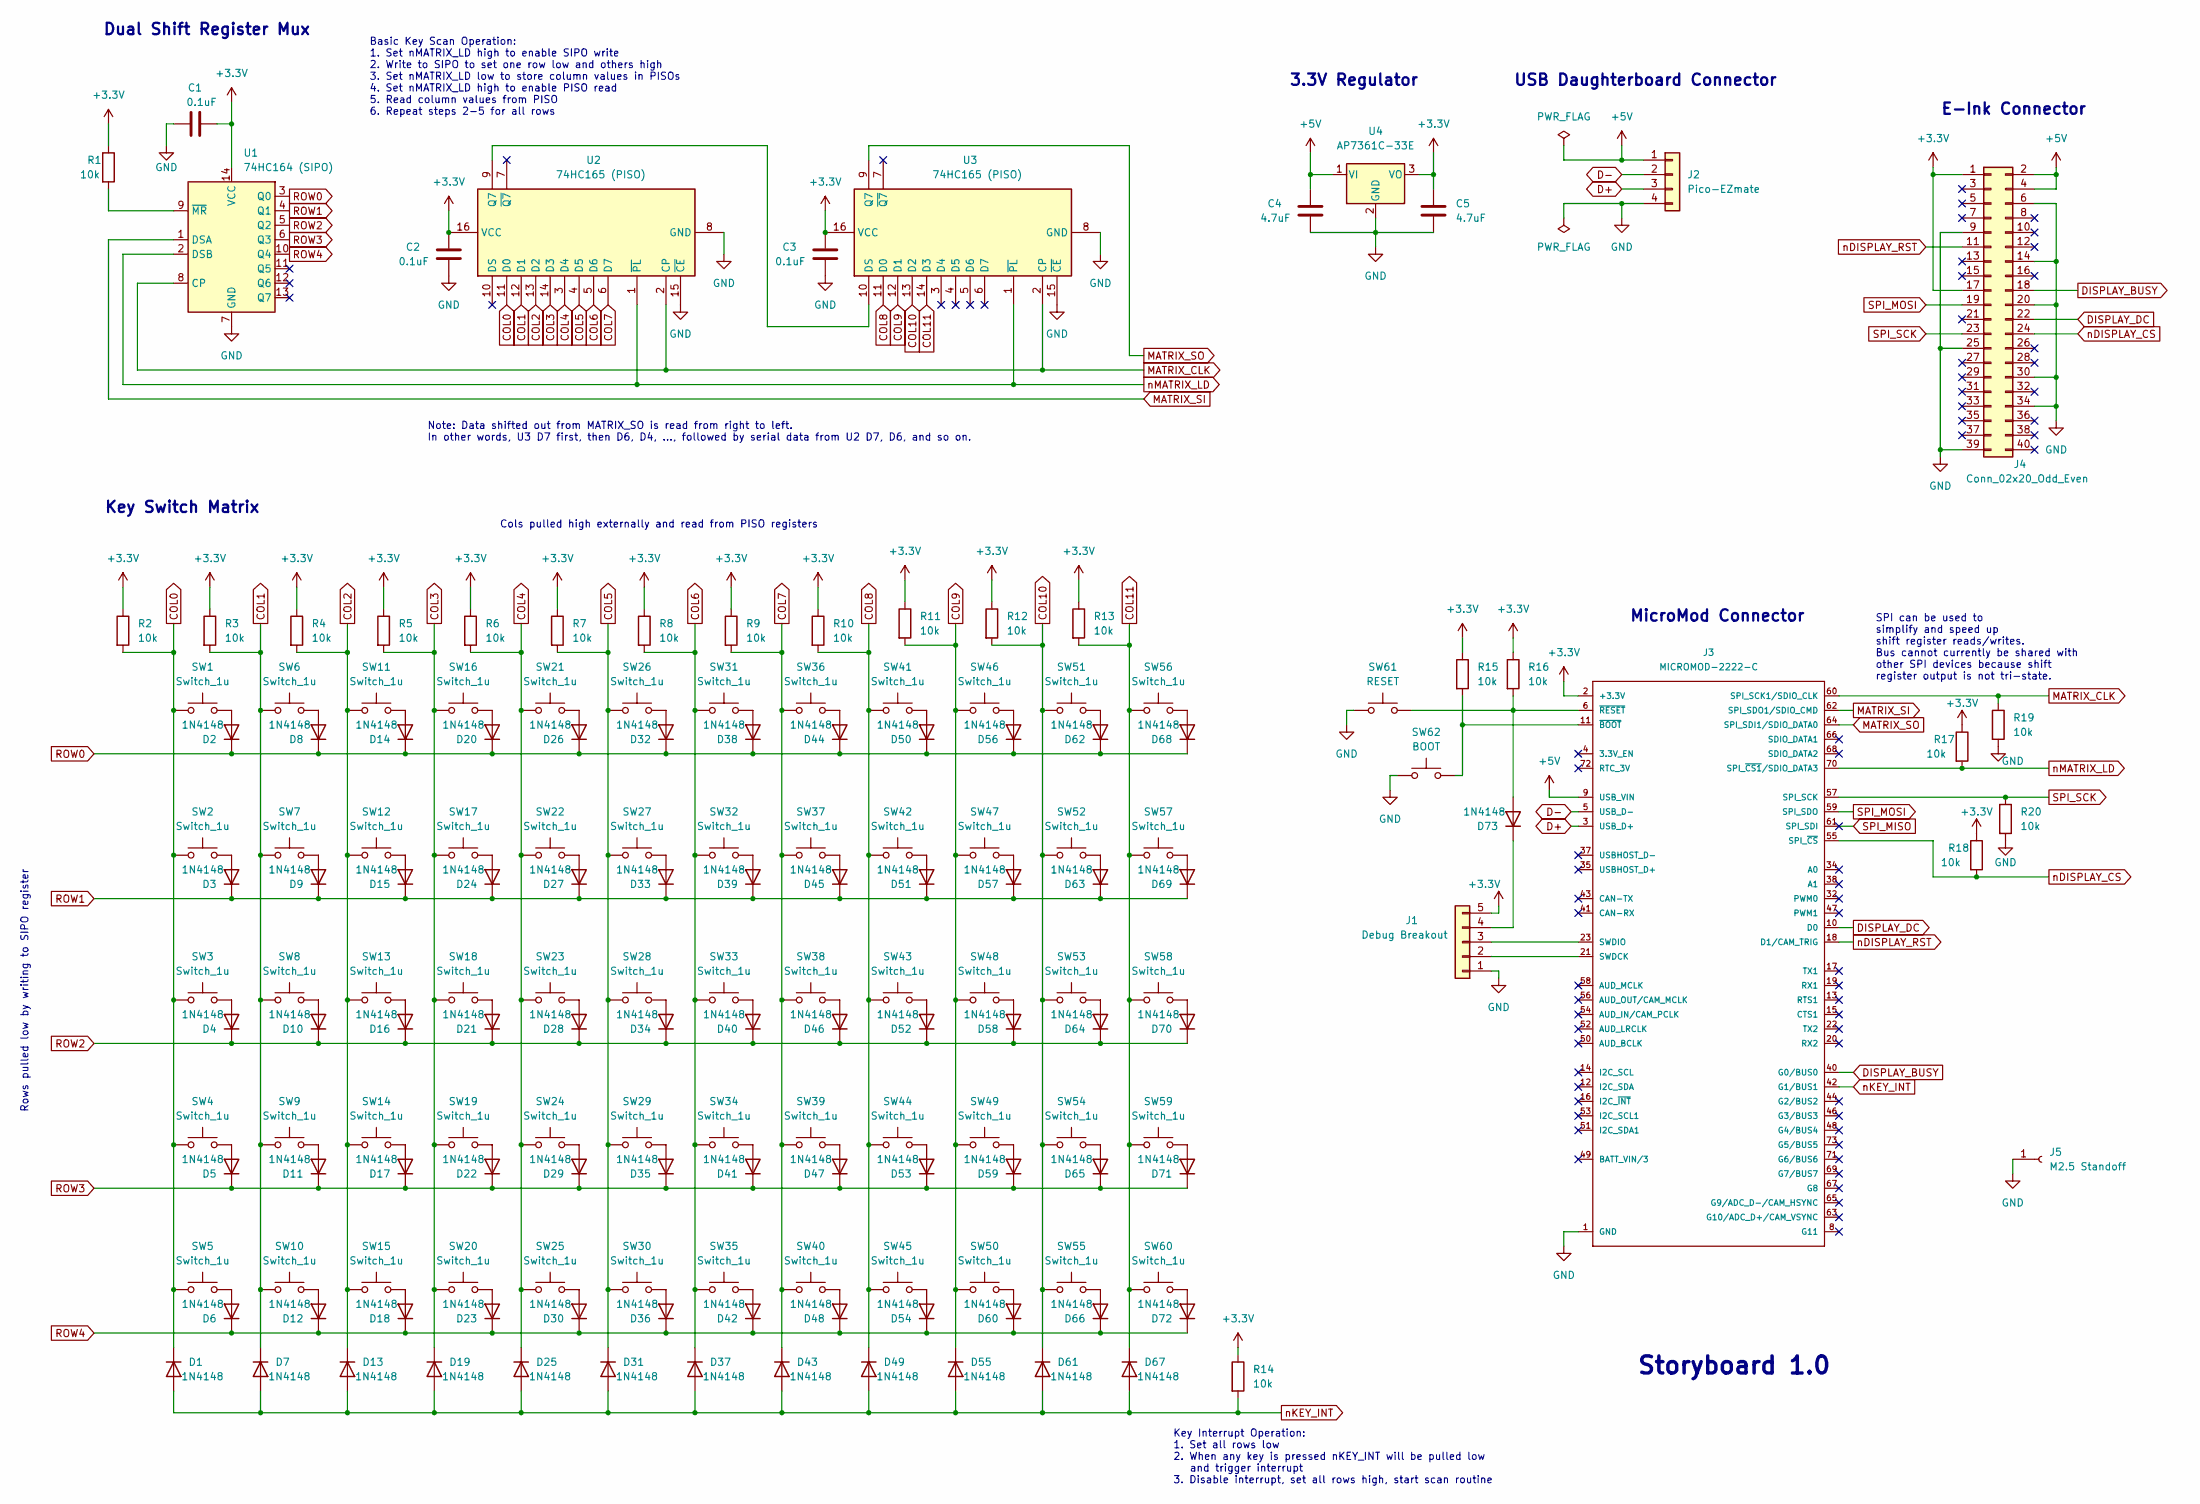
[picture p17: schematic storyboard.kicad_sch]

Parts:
C1, C2, C3: 0.1uF; C_0805_2012Metric
C4, C5: 4.7uF; C_0805_2012Metric
D1, D2, D3, D4, D5, D6, D7, D8, D9, D10, D11, D12, D13, D14, D15, D16, D17, D18, D19, D20, D21, D22, D23, D24, D25, D26, D27, D28, D29, D30, D31, D32, D33, D34, D35, D36, D37, D38, D39, D40, D41, D42, D43, D44, D45, D46, D47, D48, D49, D50, D51, D52, D53, D54, D55, D56, D57, D58, D59, D60, D61, D62, D63, D64, D65, D66, D67, D68, D69, D70, D71, D72, D73: 1N4148; D_SOD-523
J1: Debug Breakout; PinHeader_1x05_P2.54mm_Vertical
J2: Pico-EZmate; Pico-EZmate 4-pin
J3: MICROMOD-2222-C; SparkFun-MicroMod-M.2-CONNECTOR-E
J4: Conn_02x20_Odd_Even; Waveshare_ePaper_HAT_352
J5: M2.5 Standoff; Micromod-Standoff
R1, R2, R3, R4, R5, R6, R7, R8, R9, R10, R11, R12, R13, R14, R15, R16, R17, R18, R19, R20: 10k; R_0805_2012Metric
SW1, SW2, SW3, SW4, SW5, SW6, SW7, SW8, SW9, SW10, SW11, SW12, SW13, SW14, SW15, SW16, SW17, SW18, SW19, SW20, SW21, SW22, SW23, SW24, SW25, SW26, SW27, SW28, SW29, SW30, SW31, SW32, SW33, SW34, SW35, SW36, SW37, SW38, SW39, SW40, SW41, SW42, SW43, SW44, SW45, SW46, SW47, SW48, SW49, SW50, SW51, SW52, SW53, SW54, SW55, SW56, SW57, SW58, SW59, SW60: Switch_1u; Kailh_socket_MX
SW61: RESET; SW_PUSH_6mm
SW62: BOOT; SW_PUSH_6mm
U1: 74HC164 (SIPO); SOIC-14_3.9x8.7mm_P1.27mm
U2, U3: 74HC165 (PISO); SOIC-16_3.9x9.9mm_P1.27mm
U4: AP7361C-33E; SOT-223-3_TabPin2

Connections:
+3.3V: C1.2, C2.1, C3.1, C5.1, J1.5, J3.2 (+3.3V), J3.74 (+3.3V), J4.1, J4.17, R1.1, R2.1, R3.1, R4.1, R5.1, R6.1, R7.1, R8.1, R9.1, R10.1, R11.1, R12.1, R13.1, R14.1, R15.1, R16.1, R17.1, R18.1, U1.14 (VCC), U2.16 (VCC), U3.16 (VCC), U4.3 (VO)
+5V: C4.1, J2.1, J3.9 (USB_VIN), J4.2, J4.4, U4.1 (VI)
COL0: D1.1 (K), R2.2, SW1.1, SW2.1, SW3.1, SW4.1, SW5.1, U2.11 (D0)
COL1: D7.1 (K), R3.2, SW6.1, SW7.1, SW8.1, SW9.1, SW10.1, U2.12 (D1)
COL2: D13.1 (K), R4.2, SW11.1, SW12.1, SW13.1, SW14.1, SW15.1, U2.13 (D2)
COL3: D19.1 (K), R5.2, SW16.1, SW17.1, SW18.1, SW19.1, SW20.1, U2.14 (D3)
COL4: D25.1 (K), R6.2, SW21.1, SW22.1, SW23.1, SW24.1, SW25.1, U2.3 (D4)
COL5: D31.1 (K), R7.2, SW26.1, SW27.1, SW28.1, SW29.1, SW30.1, U2.4 (D5)
COL6: D37.1 (K), R8.2, SW31.1, SW32.1, SW33.1, SW34.1, SW35.1, U2.5 (D6)
COL7: D43.1 (K), R9.2, SW36.1, SW37.1, SW38.1, SW39.1, SW40.1, U2.6 (D7)
COL8: D49.1 (K), R10.2, SW41.1, SW42.1, SW43.1, SW44.1, SW45.1, U3.11 (D0)
COL9: D55.1 (K), R11.2, SW46.1, SW47.1, SW48.1, SW49.1, SW50.1, U3.12 (D1)
COL10: D61.1 (K), R12.2, SW51.1, SW52.1, SW53.1, SW54.1, SW55.1, U3.13 (D2)
COL11: D67.1 (K), R13.2, SW56.1, SW57.1, SW58.1, SW59.1, SW60.1, U3.14 (D3)
D+: J2.3, J3.3 (USB_D+)
D-: J2.2, J3.5 (USB_D-)
DISPLAY_BUSY: J3.40 (G0/BUS0), J4.18
DISPLAY_DC: J3.10 (D0), J4.22
GND: C1.1, C2.2, C3.2, C4.2, C5.2, J1.1, J2.4, J3.1 (GND), J3.7 (GND), J3.33 (GND), J3.36 (GND), J3.39 (GND), J3.45 (GND), J3.75 (GND), J4.6, J4.9, J4.14, J4.20, J4.25, J4.30, J4.34, J4.39, J5.1, R19.2, R20.2, SW61.1, SW62.1, U1.7 (GND), U2.8 (GND), U2.15 (~CE), U3.8 (GND), U3.15 (~CE), U4.2 (GND)
MATRIX_CLK: J3.60 (SPI_SCK1/SDIO_CLK), R19.1, U1.8 (CP), U2.2 (CP), U3.2 (CP)
MATRIX_SI: J3.62 (SPI_SDO1/SDIO_CMD), U1.1 (DSA)
MATRIX_SO: J3.64 (SPI_SDI1/SDIO_DATA0), U3.9 (Q7)
unnamed: D2.2 (A), SW1.2
unnamed: D3.2 (A), SW2.2
unnamed: D4.2 (A), SW3.2
unnamed: D5.2 (A), SW4.2
unnamed: D6.2 (A), SW5.2
unnamed: D8.2 (A), SW6.2
unnamed: D9.2 (A), SW7.2
unnamed: D10.2 (A), SW8.2
unnamed: D11.2 (A), SW9.2
unnamed: D12.2 (A), SW10.2
unnamed: D14.2 (A), SW11.2
unnamed: D15.2 (A), SW12.2
unnamed: D16.2 (A), SW13.2
unnamed: D17.2 (A), SW14.2
unnamed: D18.2 (A), SW15.2
unnamed: D20.2 (A), SW16.2
unnamed: D21.2 (A), SW18.2
unnamed: D22.2 (A), SW19.2
unnamed: D23.2 (A), SW20.2
unnamed: D24.2 (A), SW17.2
unnamed: D26.2 (A), SW21.2
unnamed: D27.2 (A), SW22.2
unnamed: D28.2 (A), SW23.2
unnamed: D29.2 (A), SW24.2
unnamed: D30.2 (A), SW25.2
unnamed: D32.2 (A), SW26.2
unnamed: D33.2 (A), SW27.2
unnamed: D34.2 (A), SW28.2
unnamed: D35.2 (A), SW29.2
unnamed: D36.2 (A), SW30.2
unnamed: D38.2 (A), SW31.2
unnamed: D39.2 (A), SW32.2
unnamed: D40.2 (A), SW33.2
unnamed: D41.2 (A), SW34.2
unnamed: D42.2 (A), SW35.2
unnamed: D44.2 (A), SW36.2
unnamed: D45.2 (A), SW37.2
unnamed: D46.2 (A), SW38.2
unnamed: D47.2 (A), SW39.2
unnamed: D48.2 (A), SW40.2
unnamed: D50.2 (A), SW41.2
unnamed: D51.2 (A), SW42.2
unnamed: D52.2 (A), SW43.2
unnamed: D53.2 (A), SW44.2
unnamed: D54.2 (A), SW45.2
unnamed: D56.2 (A), SW46.2
unnamed: D57.2 (A), SW47.2
unnamed: D58.2 (A), SW48.2
unnamed: D59.2 (A), SW49.2
unnamed: D60.2 (A), SW50.2
unnamed: D62.2 (A), SW51.2
unnamed: D63.2 (A), SW52.2
unnamed: D64.2 (A), SW53.2
unnamed: D65.2 (A), SW54.2
unnamed: D66.2 (A), SW55.2
unnamed: D68.2 (A), SW56.2
unnamed: D69.2 (A), SW57.2
unnamed: D70.2 (A), SW58.2
unnamed: D71.2 (A), SW59.2
unnamed: D72.2 (A), SW60.2
unnamed: D73.1 (K), J1.4
unnamed: D73.2 (A), J3.6 (~RESET), R16.2, SW61.2
unnamed: J1.2, J3.21 (SWDCK)
unnamed: J1.3, J3.23 (SWDIO)
unnamed: J3.11 (~BOOT), R15.2, SW62.2
unnamed: R1.2, U1.9 (~MR)
unnamed: U2.9 (Q7), U3.10 (DS)
ROW0: D2.1 (K), D8.1 (K), D14.1 (K), D20.1 (K), D26.1 (K), D32.1 (K), D38.1 (K), D44.1 (K), D50.1 (K), D56.1 (K), D62.1 (K), D68.1 (K), U1.3 (Q0)
ROW1: D3.1 (K), D9.1 (K), D15.1 (K), D24.1 (K), D27.1 (K), D33.1 (K), D39.1 (K), D45.1 (K), D51.1 (K), D57.1 (K), D63.1 (K), D69.1 (K), U1.4 (Q1)
ROW2: D4.1 (K), D10.1 (K), D16.1 (K), D21.1 (K), D28.1 (K), D34.1 (K), D40.1 (K), D46.1 (K), D52.1 (K), D58.1 (K), D64.1 (K), D70.1 (K), U1.5 (Q2)
ROW3: D5.1 (K), D11.1 (K), D17.1 (K), D22.1 (K), D29.1 (K), D35.1 (K), D41.1 (K), D47.1 (K), D53.1 (K), D59.1 (K), D65.1 (K), D71.1 (K), U1.6 (Q3)
ROW4: D6.1 (K), D12.1 (K), D18.1 (K), D23.1 (K), D30.1 (K), D36.1 (K), D42.1 (K), D48.1 (K), D54.1 (K), D60.1 (K), D66.1 (K), D72.1 (K), U1.10 (Q4)
SPI_MISO: J3.61 (SPI_SDI)
SPI_MOSI: J3.59 (SPI_SDO), J4.19
SPI_SCK: J3.57 (SPI_SCK), J4.23, R20.1
nDISPLAY_CS: J3.55 (SPI_~CS), J4.24, R18.2
nDISPLAY_RST: J3.18 (D1/CAM_TRIG), J4.11
nKEY_INT: D1.2 (A), D7.2 (A), D13.2 (A), D19.2 (A), D25.2 (A), D31.2 (A), D37.2 (A), D43.2 (A), D49.2 (A), D55.2 (A), D61.2 (A), D67.2 (A), J3.42 (G1/BUS1), R14.2
nMATRIX_LD: J3.70 (SPI_~CS1/SDIO_DATA3), R17.2, U1.2 (DSB), U2.1 (~PL), U3.1 (~PL)

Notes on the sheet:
E-Ink Connector
USB Daughterboard Connector
Key Interrupt Operation: 1. Set all rows low 2. When any key is pressed nKEY_INT will be pulled low and trigger interrupt 3. Disable interrupt, set all rows high, start scan routine
Note: Data shifted out from MATRIX_SO is read from right to left. In other words, U3 D7 first, then D6, D4, ..., followed by serial data from U2 D7, D6, and so on.
Storyboard 1.0
3.3V Regulator
SPI can be used to simplify and speed up shift register reads/writes. Bus cannot currently be shared with other SPI devices because shift register output is not tri-state.
Cols pulled high externally and read from PISO registers
Key Switch Matrix
Rows pulled low by writing to SIPO register
MicroMod Connector
Dual Shift Register Mux
Basic Key Scan Operation: 1. Set nMATRIX_LD high to enable SIPO write 2. Write to SIPO to set one row low and others high 3. Set nMATRIX_LD low to store column values in PISOs 4. Set nMATRIX_LD high to enable PISO read 5. Read column values from PISO 6. Repeat steps 2-5 for all rows

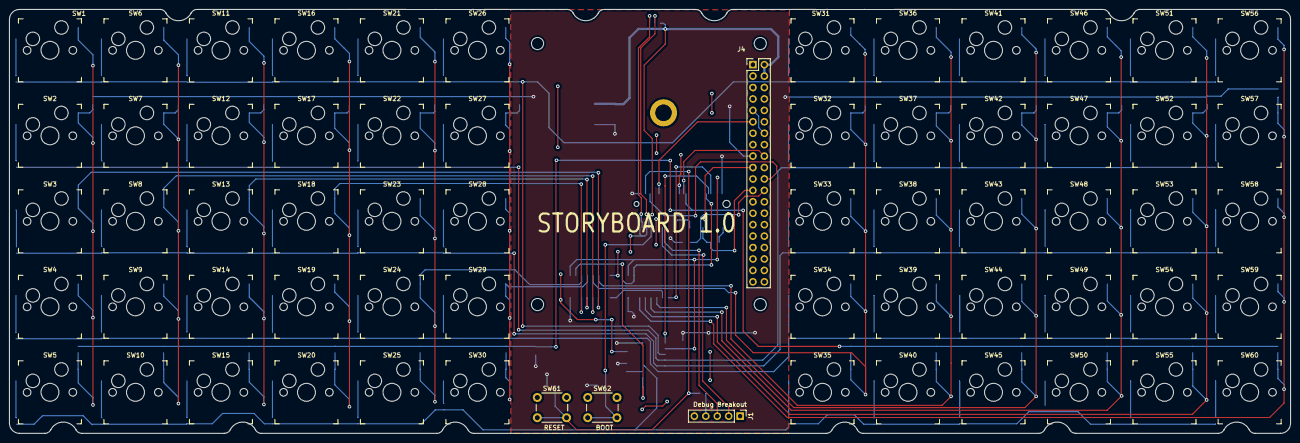
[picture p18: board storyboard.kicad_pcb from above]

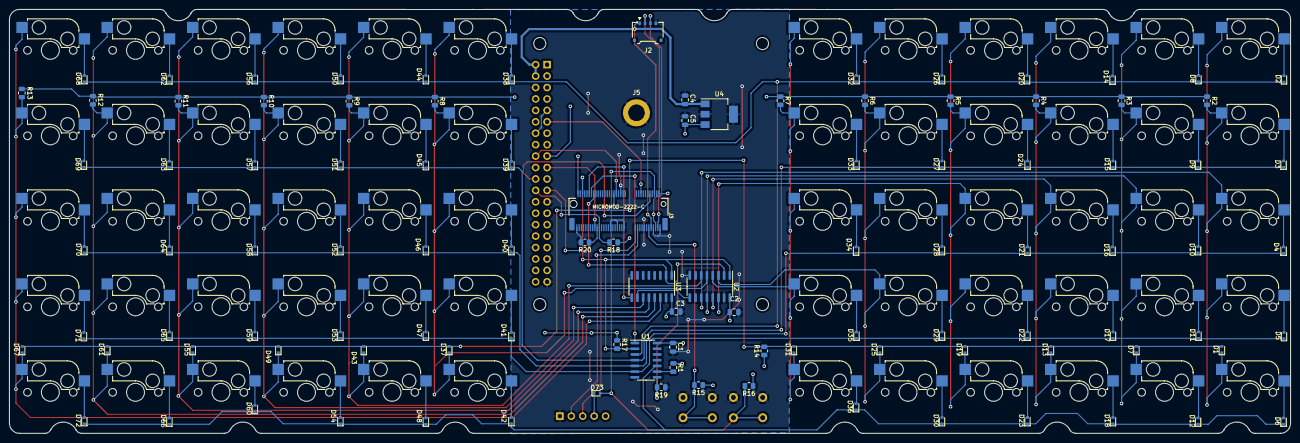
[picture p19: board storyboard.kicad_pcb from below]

Board: 2 copper layers, 284.7 x 94.2 mm, 169 parts (105 on the bottom side), 100 nets.

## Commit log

2023-07-28 Initial project upload
    PCB and schematic have not been fully tested. Not ready for manufacture.
    [storyboard-B_Cu.gbr, storyboard-B_Mask.gbr, storyboard-B_Paste.gbr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]
2023-07-28 resolve schematic parity issues
    [storyboard.kicad_pcb]
2023-07-29 add 3d step files for remaining foot prints
    [781710004.stp, MDT420E03001--3DModel-STEP-269445.STEP, Pin Header 1x10 TH Pitch 2.54mm.stp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]
2023-07-29 move production files (gerbers) to root
    [storyboard-B_Cu.gbr, storyboard-B_Mask.gbr, storyboard-B_Paste.gbr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]
2023-07-30 moved all SMD components to bottom for cheaper assembly
    [storyboard-B_Cu.gbr, storyboard-B_Mask.gbr, storyboard-B_Paste.gbr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]
2023-10-04 update latest production files
    [split-plate-B_Cu.gbl, split-plate-B_Mask.gbs, split-plate-B_Paste.gbp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]
2023-10-04 add missing BOM and assembly files
    [storyboard-bom-jlcpcb.csv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]
2023-10-04 add key scan notes to schematic
    [storyboard.kicad_sch]
2023-11-27 Add support for Tofu 60 2.0 case.
    Changes:
    1. Modify original split plate to show copper border around edges.
    2. Add support for Tofu60 2.0 top mount with a new 60% plate
    specifically designed for the Storyboard.
    3. Add gerbers for new plate and update production_files directory.
    [split-plate-B_Cu.gbl, split-plate-B_Mask.gbs, split-plate-B_Paste.gbp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]
